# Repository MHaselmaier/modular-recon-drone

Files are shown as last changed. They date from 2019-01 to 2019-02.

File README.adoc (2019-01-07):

= Modular Recon Code Repository

Implementation of the drone functionality.

== Required libraries
The project is based on the ESP32 SoC by Espressif. It is possible to use the Arduino IDE to write software for the ESP32 but many developers already experienced a bad support for the chip. The recommanded way is to use Espressif's ESP-IDF. The IDF is a SDK that contains many wrappers for the chips functionality, e.g.: 

* FreeRTOS -> real time operating system for embedded devices
** Tasks
** Semaphores
** Concurrent queues
* TCP/IP stack
** Socket implementation provided by lwip (lightweight ip)
* GPIO abstraction 
* System wide event handler

An instruction on how to install the ESP-IDF is found on their https://esp-idf.readthedocs.io/en/latest/get-started/index.html#setup-toolchain[official developers page].

== Motor Controller

== Main Control Unit
=== Basic Makefile usage
The ESP-IDF provides a pre configured Makefile environment. 

*Build*: make all

*Flash*: make flash -> Implicitly triggers build process

*Clean*: make clean

*Monitor*: make monitor -> ESP toolchain monitor. Use in own terminal as it cannot be killed

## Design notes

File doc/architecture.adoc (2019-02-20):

== Architektur
=== Main Control Unit
Die MCU ist die Hauptkontrolleinheit. Ihre Hauptaufgaben sind: 
* Hosten eines Access Points
* Hosten eines UDP-Sockets
* Hosten eines TCP-Servers
* Hosten des TWI Master

Grundlage der MCU bildet ein _Espressif ESP32_ (DevKit v.1, siehe <<fig:esp32_devkitv1>>).

.Espressif ESP32 DevKit v1 Development Board
[[fig:esp32_devkitv1, {counter:fig}]]


Im Detail stellt der ESP32 einen Access Point mit WPA2 PSK Sicherung zur Verfügung. Das Passwort AP wird hierbei mittels 
des Hardware RNG in Form einer achtstelligen positiven Ganzzahl generiert. 
Das Passwort und die SSID des AP werden auf dem Bildschirm (siehe Abbildung <<sec:oled_screen>>) dargestellt. 

==== Entwicklung
Der ESP32 ist mit 244 Mhz und zwei CPU Kernen ein relativ potenter 32 Bit Microcontroller. Zudem verfügt der Controller 
über eine Vielzahl an Schnittstellen. Neben den oben erwähnten Funktionalitäten, verfügt der ESP noch über: 

* Bluetooth 4.2 (inkl. BLE)
* 18 ADC Kanäle mit 12 bit Auflösung
* 2 DAC mit 8 bit Auflösung
* 10 Touch Sensoren (Kapazitiv)
* 4 SPI Controller
* 2 TWI Controller
* 2 I^2^S Controller
* 3 UART Controller
* SD/SDIO/MMC/eMMC Host Controller 
* CAN Bus 2.0
* Motor und LED PWM
* Hall Effekt Sensor
* Hardwarebeschleunigte Kryptografie (AES, SHA-2, RSA, ECC, RNG)

Software für den ESP32 kann mit Hilfe der Arduino IDE entwickelt werden. Jedoch ist das SDK des Herstellers, auch als ESP-IDF bezeichnet, vorzuziehen, da 
sie der Arduino IDE gegenüber wesentlich mächtiger ist. 

==== ESP-IDF
Die Installation der ESP-IDF ist unter den gängigen Betriebssystemen mit Hilfe der 
Anleitung auf der Herstellerseite (siehe <<esp_idf_install>>) unkompliziert möglich. Dem SDK liegt zusätzlich noch eine Ansammlung an Beispielprojekten, sortiert nach Modulen (Wifi, Bluetooth, GPIO, etc) bei. Diese sind, wie auch die Komponenten der SDK selbst (Header Dateien) umfangreich und gut dokumentiert. Beim Aufsetzen eines neuen Projektes empfiehlt es sich, eines der Beispielprojekte zu nehmen (im Zweifelsfall das Hello World), da die ESP-IDF bereits eine auf Make basierende Buildchain anbietet. 

Diese lässt sich mit folgenden Befehlen bedienen (aus dem Projektverzeichnis heraus):

* make menuconfig -> TUI zur Konfiguration des Projektes (sdkconfig.h)
* make all -> Bau des Projektes
* make flash -> ggf. Bau des Projektes und Flashen des ESP
* make clean -> Bereinigung des Build-Verzeichnisses
* make monitor -> Starten des pythonbasierten seriellen Monitors

Um die Buildchain des SDK ohne Einschränkungen verwenden zu können, wird eine Python 2 installation benötigt. Diese sollte entsprechend unter Verwendung von _menuconfig_ unter _SDK Tool Configuration_ -> _Python 2 Interpreter_ gesetzt werden.

Danach muss noch der serielle Port, unter dem der ESP im Betriebssystem angebunden wird, konfiguiert werden. Dies geschieht unter _Serial flasher options_ -> _Default serial port_.

Die ESP-IDF nutzt das Echtzeitbetriebssystem FreeRTOS (siehe <<freertos>>). Dieses stellt Tasks, Message Queues zur Intertaskkommunikation, Tasksynchronisationsmechanismen (Mutex, etc) zur Verfügung.

Als TCP/IP Stack wird LwIP (siehe <<lwip>>) genutzt. Es handelt sich um eine leichtgewichtige Implementierung, deren Fokus auf Embedded Systems gelegt ist. Angelehnt ist die API an die der POSIX sockets.

==== MCU Software
Die Struktur des Projektes stellt sich wie folgt dar:

* main_control_unit
** components
*** camera 
*** u8g2
** main

Für das Ansprechen der Komponenten Kamera (siehe Abschnitt <<sec:camera_module>>) und Display (siehe Abschnitt <<sec:oled_display>>) wurden 
jeweils entsprechende externe Bibliotheken verwandt (näheres in den entsprechenden Kapiteln). Diese sind, wie andere externe Bibliotheken im Allgemeinen, im Ordner _components_ abgelegt. 
Der eigentliche Code der Drohne befindet sich im Ordner _main_. Der Aufbau der eigentlichen Projektdateien ist in Abbildung <<fig:mcu_structure>> definiert.

.MCU Code Struktur
[[fig:mcu_structure, {counter:fig}]]
[ditaa, "mcu_structure"]
....
+---------+                      +---------+
| drone.c |----------------------| drone.h |
+---------+                      +---------+
                                   | | | |
        /--------------------------/ | | \----------------------------\
        |                   /--------/ \-------\                      |
        |                   |                  |                      |
+---------------+  +-----------------+  +--------------+  +-------------------------+
| accesspoint.c |  | camera_module.c |  | i2c_master.c |  | udp_motor_data_server.c |
+---------------+  +-----------------+  +--------------+  +-------------------------+
....

Zunächst werden die Komponenten initialisiert. Nach der Initialisierung werden die einzelnen Module (accesspoint.c, etc) gestartet. 
Hierbei werden entsprechend für die einzelnen Module jeweils Tasks generiert um möglichst parallel zu laufen.

===== Access Point

===== Motor Control

===== Camera 

[plantuml]
....
@startuml
Main -> init: calls
@enduml
....

=== Motor Controller
Um die beiden Motoren anzusteuern, wurde ein ATTiny25 Mikrocontroller pro Motor verwendet.
Über das TWI wird den beiden Mikrocontrollern die gewüschte Richtung und Geschwindigkeit von
der MCU mitgeteilt. Sie werden über die Adressen 0x01 und 0x02 angesprochen. Auf Abbildung
<<fig:attiny25_pinout>> sind die Pins für die Takt- (_SCL_) und Datenleitung (_SDA_) des TWIs gezeigt.
Da die ATTinys nicht über eine Hardwareimplementierung des TWIs verfügen, musste sie in Software realisiert
werden. Hierzu wurde eine bereits existierende Implementation von <<twi_implementation>> verwendet, welche
die USI Schnittstelle der Mikrocontroller passend für das TWI konfiguriert (siehe <<attiny254585>>).

.ATTiny25 Pinout
[[fig:attiny25_pinout,{counter:fig}]]
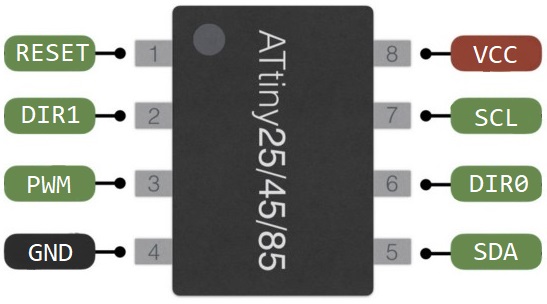
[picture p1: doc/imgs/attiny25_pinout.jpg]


Die ATTinys erwarten ein Byte, in dem die Richtung und die Geschwindigkeit kodiert sind.
Das höchstwertige Bit kodiert die Richtung. Wird eine _0_ empfangen, wird der Pin _DIR0_ auf _HIGH_
gesetzt und der Pin _DIR1_ auf _LOW_ gesetzt. Wird eine _1_ empfangen, wird enstprechend Pin _DIR0_
auf _LOW_ und Pin _DIR1_ auf _HIGH_ gesetzt. Diese beiden Pins sind nie zeitgleich _HIGH_. Durch die 
unteren sieben Bit des empfangenen Bytes wird die Geschwindigkeit in Prozent angegeben. Intern
betreiben die Mikrocontroller hiermit eine Pulsweitenmodulation, welche 127 Schritte unterstützt.
Dieses Signal wird über den Pin _PWM_ ausgegeben. Zwischen den ATTinys und dein Motoren wurde eine
H-Brücken eingebaut, um die Motoren mit 11.1V betreiben zu können. Wie die beiden Mikrocontroller 
über die H-Brücke mit den beiden Motoren verbunden ist, ist auf Abbildung <<fig:motor_controller_schematic>>
gezeigt.

.Schaltplan der Motorsteuerung
[[fig:motor_controller_schematic, {counter:fig}]]
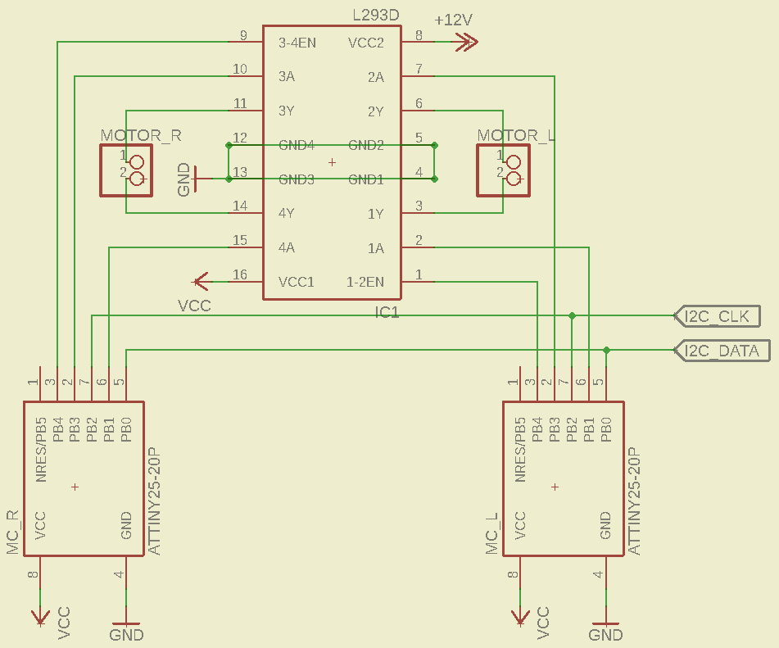
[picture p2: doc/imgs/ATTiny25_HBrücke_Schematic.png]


Der Programmcode für beide Mikrocontroller ist identisch. Die Adresse für das TWI wird
über das Define-Flag _address_ gesetzt werden. Um das Kompilieren des Programms für die 
beiden Mikrocontroller zu erleichtern, wurde ein Makefile erstellt. Durch den _make_
Befehl werden die Programm der beiden Mikrocontroller gebaut. Durch _make flash_L_ und
_make flash_R_ wird entsprechend das Programm für die linke und rechte Motorsteuerung 
auf die Mikrocontroller geschrieben. Damit das Kompilieren und Programmieren der ATTinys
funktioniert, müssen die AVR-Entwicklungstools _avr-gcc_, _avr-objcopy_ und _avrdude_ 
installiert sein. Bevor die Programme auf die Mikrocontroller geschrieben werden können,
muss sichergestellt werden, dass der Port des Programmers richtig gesetzt ist. Hierzu
kann das _-P_-Flag des _avrdude_-Befehls angepasst werden. Je nachdem, welche Programmer 
verwendet wird, muss auch das _-c_-Flag angepasst werden. In der aktuellen Version wird
davon ausgegangen, dass mit einem AVRISP programmiert wird (siehe <<arduino_programmer>>).

[[sec:camera_module]]
=== Kameramodul
Das Kameramodul basiert auf dem OV7725 VGA Sensor von Omnivision. 

.Anschluss der Kamera am ESP32
[width="75%", align="center"]
|===
|Kamera Pin |ESP32 Pin | |Kamera Pin | ESP32 Pin

|SIOC
|GPIO23
|
|SIOD
|GPIO25

|XCLK
|GPIO27
|
|VSYNC
|GPIO22

|HREF
|GPIO26
|
|PCLK
|GPIO21

|D2
|GPIO35
|
|D3
|GPIO17

|D4
|GPIO34
|
|D5
|GPIO5

|D6
|GPIO39
|
|D7
|GPIO18

|D8
|GPIO36
|
|D9
|GPIO19

|RESET
|GPIO15
|
|PWDN
| (über 10kOhm Widerstand auf GND)

|3.3V
|3.3V
|
|GND
|GND
|===

.Kameramodul OV7725
[[fig:camera_module, {counter:fig}]]
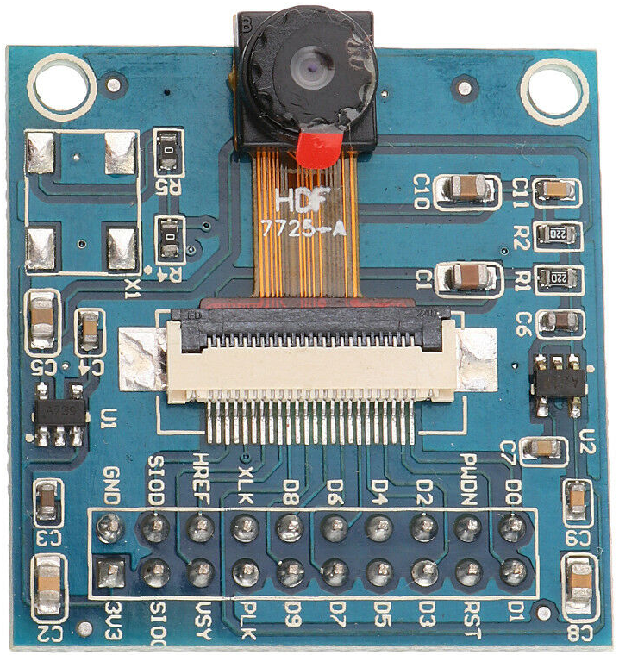
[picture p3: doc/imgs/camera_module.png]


[[sec:oled_display]]
=== Bildschirm
Verwendung findet ein monochromes OLED-Display mit einer Auflösung von 128x64 Pixel. Dieses basiert auf dem verbreiteten SSD1306 Controller. 

.Oled Diplay 128x64, SSD1306
[[fig:oled_display, {counter:fig}]]
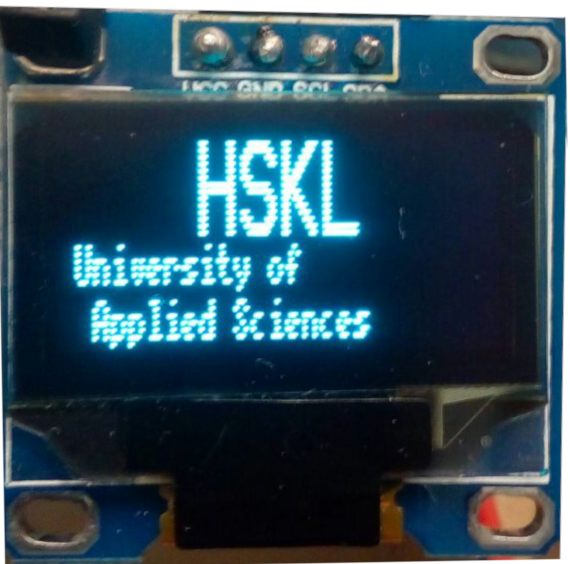
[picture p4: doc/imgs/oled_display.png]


Das Display wird hierbei über einen TWI-Bus angebunden. Entsprechend Pinout setzt sich wie folgt zusammen:

* GND: Ground, Masse
* VCC: Spannung, 3,3V - 5V
* SDL: TWI, Datenleitung
* SCL: TWI, Taktleitung

=== Stromversorgung
Im gesamten Projekt werden drei Versorgungsspannungen benötigt: 3.3V für das Kameramodul, 5V für die MCU und die Motorsteuerung und
bis zu 12V für die Motoren. Auf Abbildung <<fig:powersupply>> wird gezeigt, wie die einzelnen Versorgungsspannungen von der Batterie
erhalten werden.

.Stromversorgung
[[fig:powersupply, {counter:fig}]]
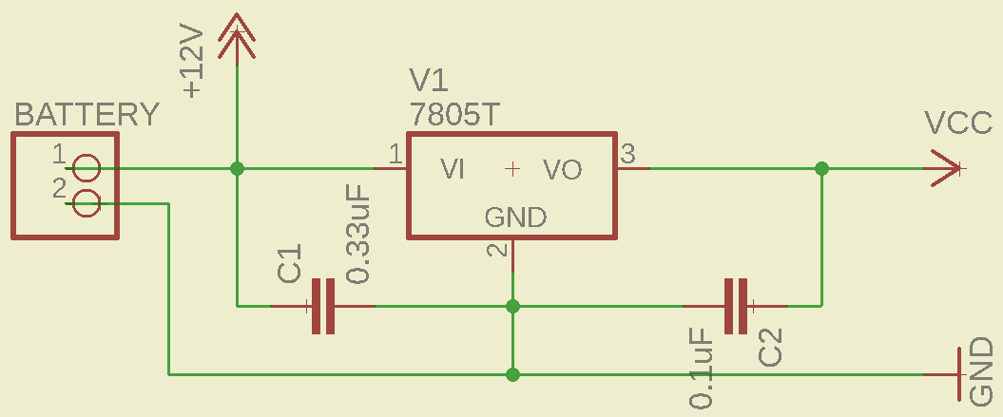
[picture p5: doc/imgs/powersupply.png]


Die Motoren werden direkt mit der Batteriespannung betrieben. Um die 5V für die MCU und die Motorsteuerung zu erhalten, wurde der
Spannungsregler 7805 verwendet. Er benötigt mindest 7V als Eingangspannung, um 5V als Ausgungsspannung zu erzeugen. Um ein Schwanken
der Betriebsspannungen zu vermeiden wurden Kondensatoren vor dem Ein- und Ausgang des Spannungsreglers platziert. Die für das
Kameramodul nötigen 3.3V werden von der MCU erzeugt. Bei der Realisierung dieses Projektes wurde sich für einen 3-Zellen LiPo-Akku
entschieden, wodurch 11.1V als Batteriespannung anliegen.

=== Schaltplan und PCB
Zu Beginn des Projekts wurden die einzelnen Komponenten auf einem Breadboard verkabelt und getestet und anschließend auf einer
Lochrasterplatine in einem Prototypen verlötet. Dieser Prototyp ist auf Abbildung <<fig:prototyp>> zu sehen.

.Lochrasterplatine
[[fig:prototyp, {counter:fig}]]
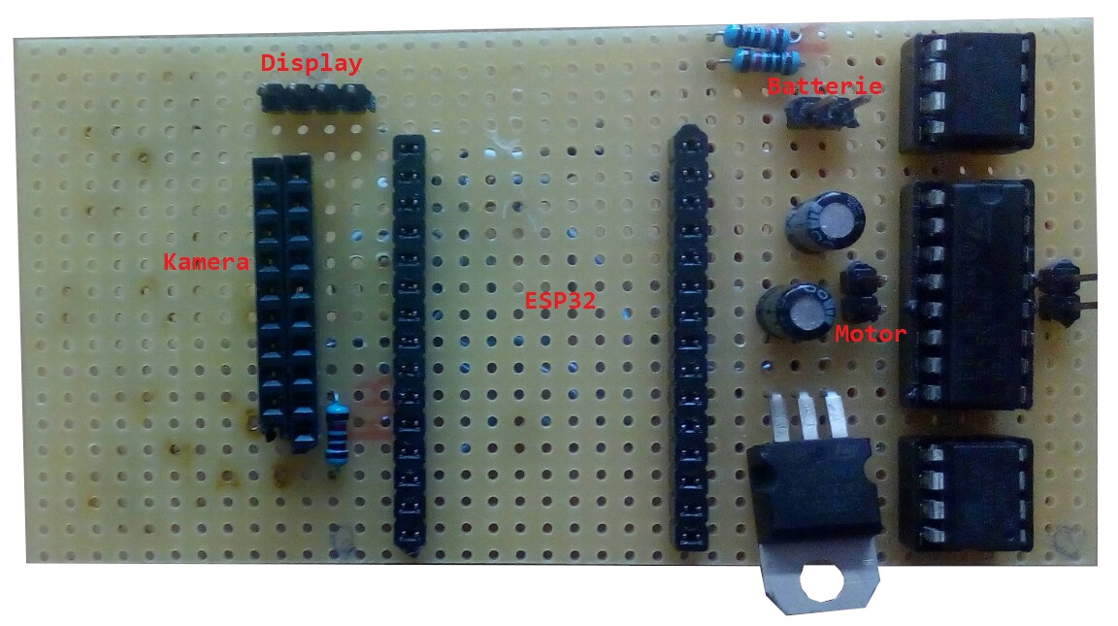
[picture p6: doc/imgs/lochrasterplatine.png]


Nachdem die Funktionalität des Aufbaus der Hardware verifiziert wurde, wurde ein PCB mit der Eagle Software von Autodesk designed
(siehe <<eagle>>). Die Eagle-Projektdateien sind im Ordner _schematic_and_pcb_ zu finden. Anschließend wurde JLCPCB (siehe <<jlcpcb>>)
mit der Fertigung des PCBs beauftragt. Das fertig bestückte PCB ist auf Abbildung <<fig:pcb>> gezeigt.

.Fertige bestücktes PCB
[[fig:pcb, {counter:fig}]]


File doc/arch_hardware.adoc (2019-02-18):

== Hardware
=== Main Control Unit
Die MCU ist die Hauptkontrolleinheit. 

=== Motor Controller
Um die beiden Motoren anzusteuern, wurde ein ATTiny25 Mikrocontroller pro Motor verwendet.
Über das TWI wird den beiden Mikrocontrollern die gewüschte Richtung und Geschwindigkeit von
der MCU mitgeteilt. Sie werden über die Adressen 0x01 und 0x02 angesprochen. Auf Abbildung
<<fig:attiny25_pinout>> sind die Pins für die Takt- (_SCL_) und Datenleitung (_SDA_) des TWIs gezeigt.
Die ATTinys erwarten ein Byte, in dem die Richtung und die Geschwindigkeit kodiert sind.

.ATTiny25 Pinout
[fig:attiny25_pinout]


Das höchstwertige Bit kodiert die Richtung. Wird eine _0_ empfangen, wird der Pin _DIR0_ auf _HIGH_
gesetzt und der Pin _DIR1_ auf _LOW_ gesetzt. Wird eine _1_ empfangen, wird enstprechend Pin _DIR0_
auf _LOW_ und Pin _DIR1_ auf _HIGH_ gesetzt. Diese beiden Pins sind nie zeitgleich _HIGH_. Durch die 
unteren sieben Bit des empfangenen Bytes wird die Geschwindigkeit in Prozent angegeben. Intern
betreiben die Mikrocontroller hiermit eine Pulsweitenmodulation, welche 127 Schritte unterstützt.
Dieses Signal wird über den Pin _PWM_ ausgegeben. Zwischen den ATTinys und dein Motoren wurde eine
H-Brücken eingebaut, um die Motoren mit 11.1V betreiben zu können. Wie die beiden Mikrocontroller 
über die H-Brücke mit den beiden Motoren verbunden ist, ist auf Abbildung <<fig:motor_controller_schematic>>
gezeigt.

.Schaltplan der Motorsteuerung
[fig:motor_controller_schematic]


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

=== Kameramodul
Das Kameramodul basiert auf dem OV7725 VGA Sensor von Omnivision. 

.Kameramodul OV7725
[fig:camera_module]


=== Bildschirm
Verwendung findet ein monochromes OLED-Display mit einer Auflösung von 128x64 Pixel. Dieses basiert auf dem verbreiteten SSD1306 Controller. 

.Oled Diplay 128x64, SSD1306
[fig:oled_display]


Das Display wird hierbei über einen TWI-Bus angebunden. Entsprechend Pinout setzt sich wie folgt zusammen:

* GND: Ground, Masse
* VCC: Spannung, 3,3V - 5V
* SDL: TWI, Datenleitung
* SCL: TWI, Taktleitung

=== Stromversorgung
Im gesamten Projekt werden drei Versorgungsspannungen benötigt: 3.3V für das Kameramodul, 5V für die MCU und die Motorsteuerung und
bis zu 12V für die Motoren. Auf Abbildung <<fig:powersupply>> wird gezeigt, wie die einzelnen Versorgungsspannungen von der Batterie
erhalten werden.

.Stromversorgung
[fig:powersupply]


Die Motoren werden direkt mit der Batteriespannung betrieben. Um die 5V für die MCU und die Motorsteuerung zu erhalten, wurde der
Spannungsregler 7805 verwendet. Er benötigt mindest 7V als Eingangspannung, um 5V als Ausgungsspannung zu erzeugen. Um ein Schwanken
der Betriebsspannungen zu vermeiden wurden Kondensatoren vor dem Ein- und Ausgang des Spannungsreglers platziert. Die für das
Kameramodul nötigen 3.3V werden von der MCU erzeugt. Bei der Realisierung dieses Projektes wurde sich für einen 3-Zellen LiPo-Akku
entschieden, wodurch 11.1V als Batteriespannung anliegen.

=== Schaltplan und PCB
Zu Beginn des Projekts wurden die einzelnen Komponenten auf einem Breadboard verkabelt und getestet und anschließend auf einer
Lochrasterplatine in einem Prototypen verlötet. Dieser Prototyp ist auf Abbildung <<fig:prototyp>> zu sehen.

.Lochrasterplatine
[fig:prototyp]


Nachdem die Funktionalität des Aufbaus der Hardware verifiziert wurde, wurde ein PCB mit der Eagle Software von Autodesk designed
(siehe <<eagle>>). Die Eagle-Projektdateien sind im Ordner _schematic_and_pcb_ zu finden. Anschließend wurde JLCPCB (siehe <<jlcpcb>>)
mit der Fertigung des PCBs beauftragt. Das fertig bestückte PCB ist auf Abbildung <<fig:pcb>> gezeigt.

.Fertige bestücktes PCB
[fig:pcb]


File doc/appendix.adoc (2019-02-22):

<<<
== Anhang

.PCB Oberseite
[[fig:pcb_front,{counter:fig}]]
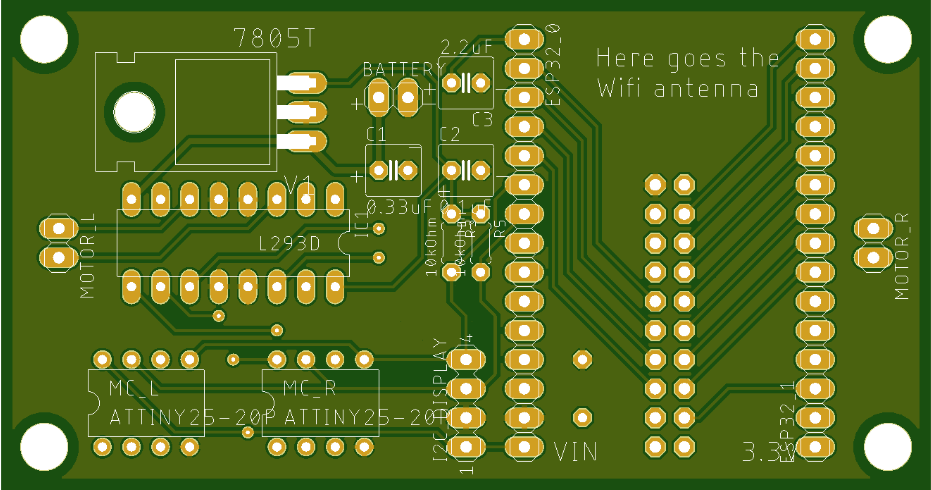
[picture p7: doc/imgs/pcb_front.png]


.PCB Unterseite
[[fig:pcb_back,{counter:fig}]]
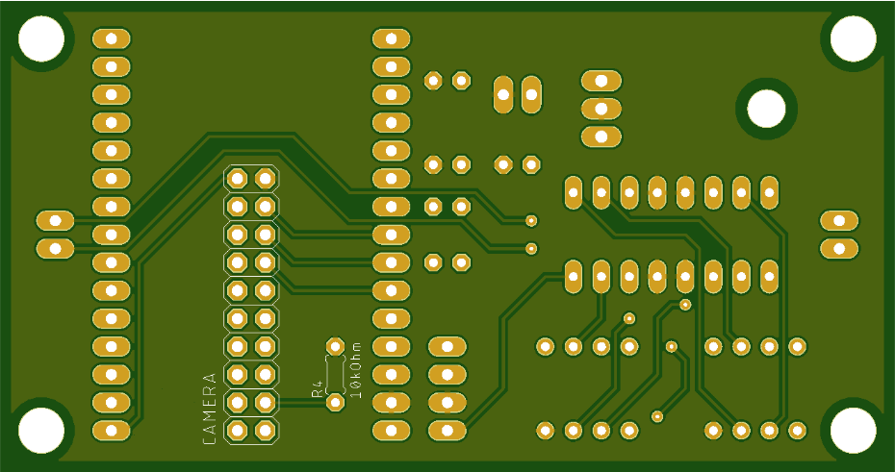
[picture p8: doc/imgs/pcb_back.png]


.Kompletter Schaltplan
[[fig:full_schematic,{counter:fig}]]
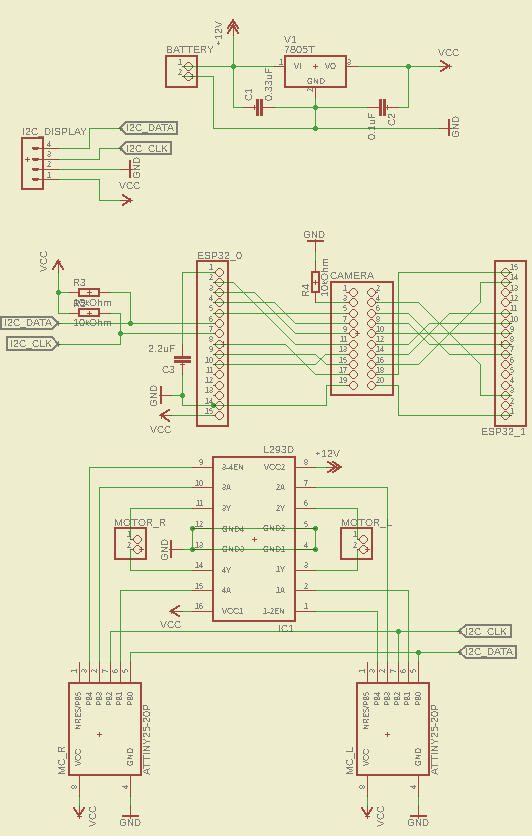
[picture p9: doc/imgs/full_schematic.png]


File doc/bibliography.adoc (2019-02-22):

<<<
[bibliography]
== Quellen
- [[[u8g2]]] Graustufenbildschirm Bibliothek: https://github.com/olikraus/u8g2
- [[[u8g2_esp]]] esp idf wrapper: https://github.com/nkolban/esp32-snippets/tree/master/hardware/displays/U8G2
- [[[esp_cam]]] esp idf Kamera Bibliothek: https://github.com/igrr/esp32-cam-demo.git
- [[[arduino_programmer]]] Arduino Uno als Programmer: https://create.arduino.cc/projecthub/arjun/programming-attiny85-with-arduino-uno-afb829
- [[[eagle]]] Eagle Software: https://www.autodesk.co.uk/products/eagle/overview
- [[[twi_implementation]]] TWI Implementation: https://github.com/rambo/TinyWire
- [[[attiny254585]]] ATTiny25/45/85 Datenblatt: https://ww1.microchip.com/downloads/en/DeviceDoc/Atmel-2586-AVR-8-bit-Microcontroller-ATtiny25-ATtiny45-ATtiny85_Datasheet.pdf
- [[[esp_idf_install]]] ESP-IDF Getting Started: https://docs.espressif.com/projects/esp-idf/en/latest/get-started/index.html
- [[[freertos]]] FreeRTOS, Dokumentation: https://www.freertos.org/Documentation/RTOS_book.html
- [[[lwip]]] LwIP TCP/IP Stack: https://savannah.nongnu.org/projects/lwip/
- [[[openscad]]] OpenSCAD: http://www.openscad.org/
- [[[ov7725]]] OV7725 Sensor: https://www.ovt.com/sensors/OV7725
- [[[esp32_kevin]]] Projekterfahrung EspressifESP32 –Fallbeispiel "Kevin", arendi, Benno Trutmann: https://www.swisst.net/fileadmin/swissTmeetings/ECC2018/Referate/2B1_Trutmann_Arendi.pdf
- [[[light_barrier_img]]] Bild, Lichtschranke, rs-online: https://de.rs-online.com/web/p/products/1254555/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
- [[[rotary_encoder_img]]] Encoder Scheibe, eckstein-shop: https://eckstein-shop.de/Adafruit-TT-Motor-Getrieb-DC-Motor-Encoder-Pack-of-2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

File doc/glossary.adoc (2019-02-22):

<<<
[glossary]
== Glossar

[glossary]
TWI:: Two Wire Interface (bekannt als I^2^C), zweiadriger Master-Slave Bus
MCU:: Main Control Unit
PCB:: Printed Ciruit Board
USI:: Universial Serial Interface
BLE:: Bluetooth Low Energy
ADC:: Analog Digital Converter
DAC:: Digital Analog Converter
PWM:: Pulse Width Modulation
AP:: Access Point
RNG:: Random Number Generator
SDK:: Software Development Kit
THT:: Through Hole Technology, Durchsteckmontage
FPS:: Frames per Second
SCCB:: Serial Camera Control Bus
SPI:: Serial Peripheral Interface

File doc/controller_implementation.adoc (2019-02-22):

== Entwicklung einer Steuerung

Aufgrund der schlichten Schnittstelle zur Drohne ist es sehr einfach, eine
beliebige Steuerung zu implementieren. Um die Drohne anzusteuern, muss sich 
zuerst mit dem bereitgestellten W-Lan-Netzwerk verbunden werden. Innerhalb
dieses Netzwerkes hat die Drohne immer die IP-Addresse _192.168.4.1_. Um 
das Kamerasignal zu erhalten, muss eine TCP-Verbindung zur Drohne über 
Port _1234_ aufgebaut werden. Die Drohne sendet das Bildsignal Byteweise
an den Client. Das übersendete Bild ist im Grayscale-Format und besitzt eine
Auflösung von 160x120 Pixeln. Um die Drohne zu steuern, müssen ihr zwei 
Bytes per UDP über Port 4242 übertragen werden. Das erste Byte steuert den linken Motor
und das zweite Byte steuert den rechten Motor (vgl. Abbildung <<fig:udp-packet>>).

[[fig:udp-packet, {counter:figure-counter}]]
[ditaa, udp-packet, align="center"]
.UDP-Paketformat
....
 <--1 bit--> <-7 bit-> <--1 bit--> <-7 bit->
+-------------------------------------------+
| Direction |  Speed  | Dircetion |  Speed  |
+-------------------------------------------+
 <----left motor-----> <----right motor---->
....

Das _Direction_ bit gibt an, ob die Motoren vorwärts (0) oder rückwärst (1) drehen.
In den sieben _Speed_ bits wird die prozentuale Geschwindigkeit definiert, also ein
Wert im Intervall [0, 100]. Um die Drohne um Hindernisse zu manövrieren, muss die 
Geschwindigkeit der beiden Motoren unterschiedlich hoch definiert werden.

Im Folgenden wird eine Referenzimplementierung der Drohnensteuerung am Beispiel
einer Android App und einer Desktopanwendung beschrieben.

=== Referenzimplementierung für Android

Zur Steuerung der Recon Drone wurde eine simple Android App entwickelt.
Sie besteht im Grunde aus zwei Ansichten, eine zum Verbinden mit der Drohne
und eine zum Steuern der Drohne. Beide Ansichten sind auf Abbildung <<fig:app>>
gezeigt. Die App sucht nach dem W-Lan-Netzwerk, das von der Drohne bereitgestellt
wird. Damit W-Lan-Netzwerke gesucht werden können, muss der Standort-Service des
Smartphones aktiviert sein. Wurde das Netzwerk gefunden, wird das Passwort zum 
Verbinden verlangt. Wurde das Passwort eingegeben und der "Verbinden"-Button 
gedrückt, baut die App die Verbindung zur Drohne auf. Damit die App mit der Drohne
kommunizieren kann, muss das mobile Internet deaktiviert sein. Diese Funktionalität
wird durch die _ReconDroneConnection_-Klasse realisiert (vgl. Abbildung <<fig:classdiagram>>).
Hat sich das Smartphone mit der Drohne verbunden, wird automatisch zur nächsten Ansicht der
App gewechselt, welche durch die _ReconDrone_-Klasse realisiert wird.

.Ansichten der App
[[fig:app,{counter:fig}]]
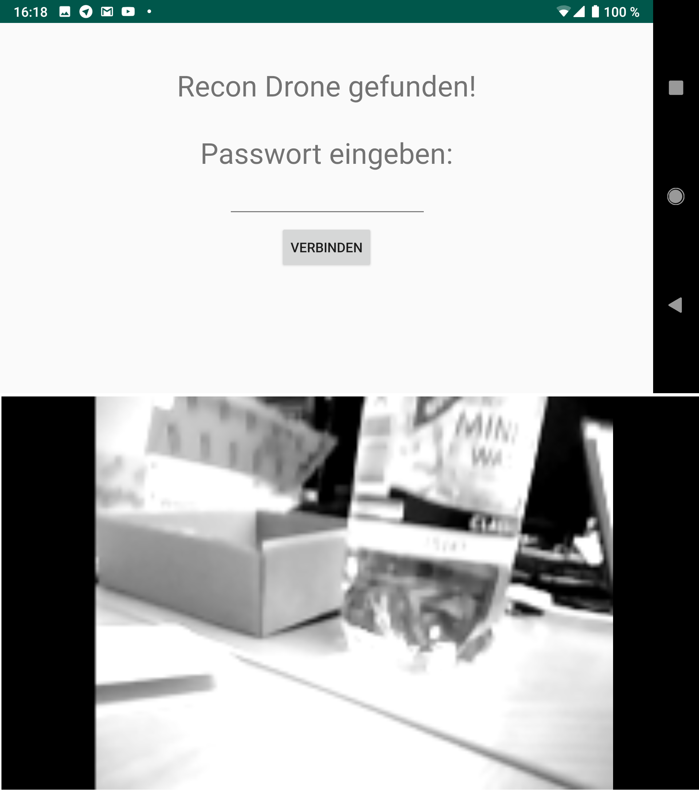
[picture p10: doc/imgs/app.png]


Aus dieser zweiten Ansicht kann die Drohne gesteuert werden und das Kamerasignal 
eingesehen werden. Die Steuerung wird von der _TouchController_-Klasse implementiert.
Die Touchevents des Benutzer werden in der _onTouch()_-Methode verarbeitet. In ihr 
werden die Startpositionen und die aktuellen Positionen der Touchbewegungen verarbeitet und 
in den Attributen _startingPositions_ und _currentPositions_ zwischengespeichert.
Die komplette rechte Hälfte des Bildschirms dient zur Beschleunigung
der Drohne. Je weiter der Finger vom Startpunkt der Touchbewegung entfernt ist, desto 
schneller bewegt sich die Drohne. Die linke Hälfte des Bildschirms dient zur Lenkung
der Drohne. In den Attributen _accerleration_ und _steering_ wird die ID des jeweiligen 
Touchevents gespeichert. Wenn kein Touchevent vorliegt, enthalten die beiden Attribute
den Wert -1. Alle 50 Millisekunden wird die Methode _sendControllerUpdate()_ aufgerufen,
welche der Drohne die Steuersignale sendet. Es werden zwei Bytes übertragen, die jeweils 
die Geschwindigkeit und Richtung für einen Motor definieren. Die beiden Bytes werden in 
den Methoden _setAcceleration()_, _setSteering()_, _setDirection()_ und _adjustForInPlaceTurn()_
befüllt.

[[fig:classdiagram,{counter:fig}]]
[plantuml, diagram-classes, png, align="center"]
.Klassendiagramm
....
@startuml
skinparam classAttributeIconSize 0
class ReconDroneConnection extends Activity {
    - status: TextView
    - passwordLabel: TextView
    - password: EditText
    - connect: Button
    - wifiManager: WifiManager
    - handler: Handler
    - removeReconDroneNetwork()
    - foundReconDrone()
    - lostReconDrone()
    - searchForReconDrone()
}
class ReconDrone extends Activity {
    - enableFullScreen()
}
class TouchController implements OnTouchListener {
    - context: Context
    - acceleration: int
    - steering: int
    - startingPositions: float[]
    - currentPositions: float[]
    + TouchController(context: Context)
    + onTouch(view: View, event: MotionEvent): boolean
    - getSideOfScreen(x: float): SIDE_OF_SCREEN
    - sendControllerUpdate()
    - setAcceleration(buffer: byte[])
    - setSteering(buffer: byte[])
    - setDirection(buffer: byte[])
    - adjustForInPlaceTurn(buffer: byte[])
}
enum SIDE_OF_SCREEN {
    LEFT
    RIGHT
}
class CameraFeed {
    - imageView: ImageView
    - handler: Handler
    - backgroundThread: Thread
    + CameraFeed(imageView: ImageView)
    + startFeed()
}

ReconDrone *-- TouchController : controller
TouchController +-- SIDE_OF_SCREEN
ReconDrone *-- CameraFeed : feed
@enduml
....

Das Kamerasignal der Drohne wird in der _CameraFeed_-Klasse verarbeitet. Sie nimmt in
ihrem Konstruktor das _ImageView_-Objekt entgegen, in dem sie das Kamerasignal anzeigen
soll. Sie startet einen Hintergrundthread, in dem die einzelnen Bilder empfangen werden
und wandelt die Byte-Daten in ein Bitmap um. Da in Android das User-Interface nicht aus
einem Hintergrundthread angepasst werden kann, wird ein _Handler_ verwendet, der das
Bitmap im _ImageView_ anzeigt.

Um die Android App zu installieren, muss die APK-Datei auf das Smartphone übertragen werden.
Sie befindet sich im Ordner _android_app/app/build/outputs/apk/debug_. Um sie zu installieren
muss in den Einstellungen des Smartphones die Installation von Apps aus unsicheren Quellen
erlaubt werden. Auf dem Smartphone muss mindestens Android 5.0 installiert sein. Die App wurde
unter Android 9.0 getestet.

=== Referenzimplementierung Desktop
Auch für den Desktop wurde eine simple Referenzimplementierung unter Verwendung des QT-Frameworks (QML) entwickelt. 
Diese baut nach dem Starten direkt eine Verbindung zum UDP- und TCP-Socket der Drohne auf. Zur Steuerung der Drohne bietet die Oberfläche zwei Slider an. Der obere regelt die Geschwindigkeit der Motoren von -100% bis 100%. Mit dem zweiten Slider, dem Balancer, kann die Richtung bestimmt werden, indem einer der Motoren verlangsamt wird.

[[fig:qt_drone_control, {counter:fig}]]
.Bedienoberfläche, DroneControl QT-Applikation
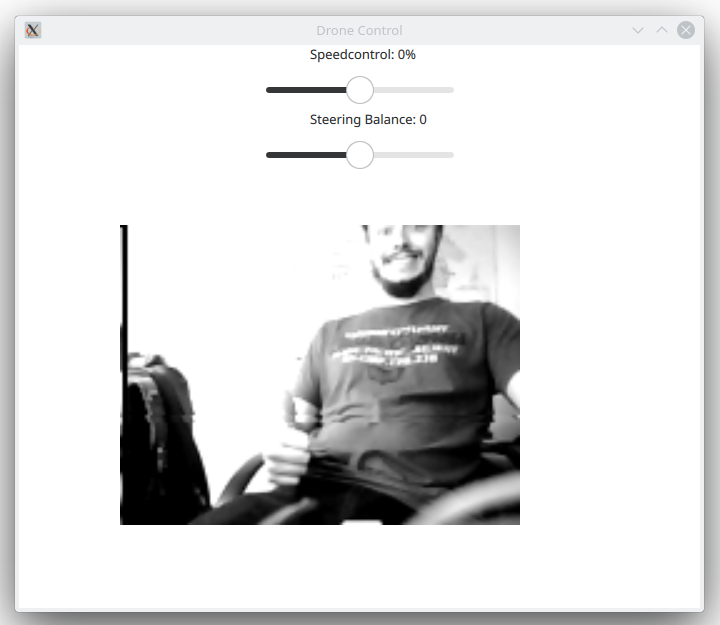
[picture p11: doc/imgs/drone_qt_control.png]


Neben der Steuerung über die Slider, lässt sich die Drohne auch mittels Gamepad steuern (siehe Abbildung <<fig:gamepad>>). Die Geschwindigkeit wird mit Hilfe der y-Achse des rechten Analogsticks gesteuert und die Balance, also die Richtung, mittels der x-Achse des linken Analogsticks. Auch eine rudimentäre Steuerung mittels Pfeiltasten ist möglich (jedoch nicht zu empfehlen).

[[fig:gamepad, {counter:fig}]]
.Verwendeter Gamepad-Typ
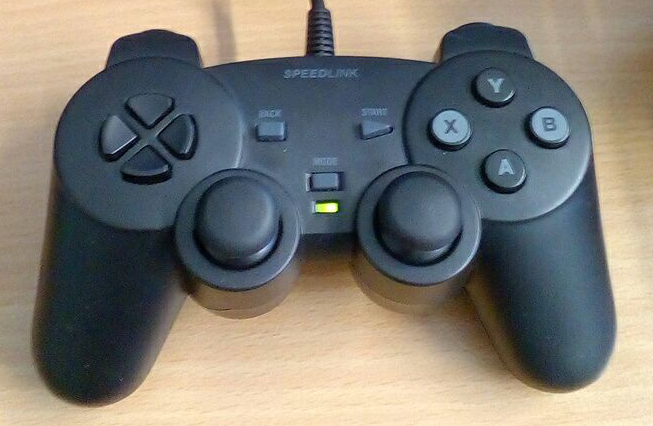
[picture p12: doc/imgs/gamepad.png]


Zum Bauen der Anwendung wird ein C++ Compiler, sowie das QT-Framework benötigt. Zusätzlich sollte die Zusatzbibliothek _qt5-gamepad_ installiert werden, da die Gamepad-Steuerung darauf basiert.

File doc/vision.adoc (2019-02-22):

== Ausblick
Auf Basis des derzeitigen Entwicklungsstands der Drohne lassen sich weitere Zusatzfunktionen und Verbesserungen implementieren. Einige 
Ideen sollen im Folgenden präsentiert werden.

=== Gehäuse
Derzeit ist das Chassis der Drohne noch im Prototypenzustand, gefertigt aus Stahllochblechprofilen. Diese Bauart ist zum Einen relativ schwer und bietet keinen Rundumschutz.
Es bietet sich deshalb an, ein Gehäuse mittels 3D-Druck anzufertigen. Während des Projektes wurde bereits eine erste Version des Gehäuses mittels CAD Software (siehe <<openscad>>)  modeliert. Dieses kann evaluiert und gedruckt werden oder durch ein anderes, völlig neues Design ersetzt werden. 

=== Verpolschutz
Im aktuellen Stand wird der LiPo-Akku mittels _Male Headern_ am PCB der Drohne angeschlossen. Der Akku verfügt über eine Buchse vom Typ _JST RCY_. Zum Einen könnte ein entsprechender _Female_ Verbinder für THT Platinen verbaut werden, um eine richtige Polung beim Anschließen zu garantieren. 
Zum Anderen kann mit Hilfe eines Brückengleichrichters (siehe Abbildung <<fig:bridge_rectifier>>) hinter dem Akkuanschluss ein Schutz vor Verpolung garantiert werden. 

.Diodenbrückengleichrichter
[[fig:bridge_rectifier, {counter:fig}]]
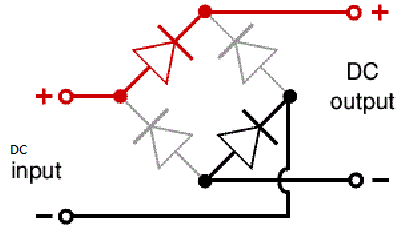
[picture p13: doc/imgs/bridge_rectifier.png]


Die Funktionsweise der Brücke ist relativ simple. Unabhängig davon, wie der Strom angelegt wird, schließt die Konfiguration der Dioden stets so, dass am Ausgang der Brücke Plus und Minus immer gleich anliegen. 
Eine Diode hat entsprechend die Eigenschaft, Strom in eine Richtung hin passieren zu lassen, während sie in entgegengesetzter Richtung den Stromfluss sperrt.

=== Raspberry PI zero W
Alternativ kann als MCU der Raspberry PI zero W evaluiert werden. Vorteil dieses Einplatinencomputers im Gegensatz zum ESP32 ist der wesentlich größere RAM, der das Puffern größerer Kamerabilddaten ermöglicht (siehe Abschnitt <<sec::camera_module>>).

=== Alternative Stromversorgung
Aktuell wird ein linearer Spannungsregler verwendet, um die hohe Batteriespannung von 11.1V auf die 5V
zu reduzieren, die von der MCU und den ATTinys benötigt werden. Hierbei wird sehr viel Energie
in Form von Wärme verschwendet. Dies beeinflusst die Batterielaufzeit der Drohne negativ. Weiterhin
besteht die Möglichkeit, dass der Spannungsregler überhitzt, in welchem Fall er sich abschalten
würde. Erst wenn er weit genug abgekühlt ist, gibt er wieder 5V aus. Dies würde zum Abschalten der
Drohne führen. Alternativ könnte ein _Step-Down-Converter_ oder auch _Buck-Converter_ verwendet werden.
Im Vergleich zu einem linearen Spannungsregler wird verschwendet diese Variante weniger Energie und erhöht
somit die Batterielaufzeit der Drohne. Allerdings wird die Schaltung etwas komplexer und die benötigten 
Komponenten kosten etwas mehr als ein linearer Spannungsregler.

[[sec:vision_external_ram]]
=== Externer SPI RAM
Das Kamerabild, das von der Drohne übertragen wird, kann aktuell eine maximale Auflösung von 320x240 Pixeln 
unterstützen, wenn es im Grayscale-Format übertragen wird. Diese Einschränkungen sind auf den begrenzten
internen RAM des ESP32 zurückzuführen. Er besitzt eine Größe von 320KB, welche sich in zwei Teile
unterteilt. Aufgrund von technischen Einschränkungen können maximal 160KB statisch allokiert werden. Die restlichen
160KB können nur während der Laufzeit dynamisch allokiert werden (vgl. <<esp32_kevin>>). Bei einer Auflösung von 320x240 Pixeln und einem
Byte für den Grauwert eines Pixels benötigt ein Bild bereits 76.8KB, um es vor dem Senden zwischenzuspeichern.
Ein farbiges Bild ist nicht möglich, da dies Aufgrund der 3 Bytes pro Pixel, eines pro Farbkanal, bei einer Größe von
230.4KB liegen würde. Wird versucht ein Byte-Array dieser Größe zu allokieren, gibt der ESP32 eine Fehlermeldung aus.
Es ist jedoch möglich, den internen RAM des ESP32 um einen externen RAM zu erweiteren, der über das SPI-Interface
angeschlossen wird. Ist der gewählte externe RAM groß genug, kann ein farbiges Bild in der maximalen Auflösung
des Sensors von 640x480 Pixeln aufgenommen werden. Hierfür werden 921,6KB benötigt.

=== Drehzahlkorrektur der Motordrehzahl
Da die Motoren bedingt durch geringfügige Fertigungsunterschiede (unterschiede in der Erregerwicklung, etc) laufen die Motoren bei gleichem PWM Signal nicht identisch schnell. Entsprechend hat die Drohne die Tendenz bei Geradeausfahrten in eine bestimmte Richtung zu fahren. 
Um diesem Verhalten entgegenzuwirken, muss der ESP32 anhand der tatsächlichen Drehzahl der Motoren Korrekturwerte an die Motorcontroller übergeben. Um die Drehzahl bei einem Gleichstrommotor zu ermitteln, können beispielsweise folgende Verfahren angewandt werden: 

*Back EMF - Back Electromotive Force*: Da ein PWM Signal den Motor nicht durchgehend mit Spannung versorgt, sondern nur in Intervalen, befindet sich der Motor auch immer in Phasen, in denen er keine Spannungsversorgung erhält. Bedingt durch die Trägheit dreht der Motor sich noch eine gewisse Zeit weiter. In dieser Phase generiert der Motor eine Spannung durch elektrische Induktion (siehe Induktionsgesetze von Michael Faraday, Joseph Henry und Hans Christian Ørsted und Lenzsche Regel nach Emil Lenz), dem Back EMF. Diese Spannung kann entsprechend von einem ADC eingelesen und interpretiert werden. Es ist zu beachten, dass die Spannung ggf. erst mittels Spannungsteiler auf ein für den Microcontroller sicher messbaren Spannungsbereich herunter bricht (max. 5V).

*Rotary Encoder*: Beim Rotary Encoder bzw. Drehgeber handelt es sich im einfachsten Fall um eine Scheibe mit Schlitzen in gleichen Abständen zueinander, wie in Abbildung <<fig:rotary_wheel>> gezeigt. Diese Scheibe ist an der Welle des Motors angebracht. 

.Drehgeber, Scheibe, <<rotary_encoder_img>>
[[fig:rotary_wheel, {counter:fig}]]
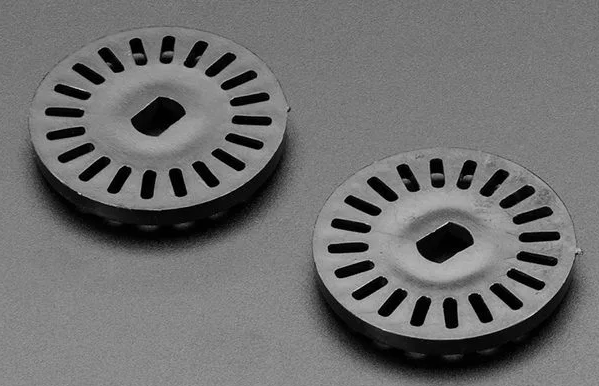
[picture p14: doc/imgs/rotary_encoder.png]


Die Schreibe dreht sich hierbei zwischen einer Lichtschranke, wie in Abbildung <<fig:light_barrier>>, die wiederum aufgrund der Schlitze in der Scheibe abwechselnt eine Spannung ausgibt oder nicht. Ausgelesen mit einem GPIO-Pin ergibt sich hieraus ein Signal in Sägezahnform, wobei die Frequenz der Flankenwechsel der Umdrehung des Motors entspricht.

.Drehgeber, Lichtschranke, <<light_barrier_img>>
[[fig:light_barrier, {counter:fig}]]
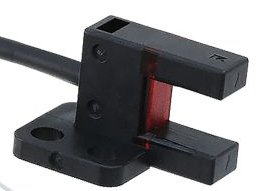
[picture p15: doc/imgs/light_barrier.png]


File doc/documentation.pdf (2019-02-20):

# Modular Recon Drone

# Dokumentation

Matthias Haselmaier, B.Sc. und Andreas M. Brunnet, B.Sc.

# Table of Contents

# Vorwort Architektur

# Main Control Unit

Die MCU ist die Hauptkontrolleinheit.

# Motor Controller

Um die beiden Motoren anzusteuern, wurde ein ATTiny25 Mikrocontroller pro Motor verwendet. Über das TWI wird den beiden Mikrocontrollern die gewüschte Richtung und Geschwindigkeit von der MCU mitgeteilt. Sie werden über die Adressen 0x01 und 0x02 angesprochen. Auf Abbildung {counter:fig} sind die Pins für die Takt- (SCL) und Datenleitung (SDA) des TWIs gezeigt. Da die ATTinys nicht über eine Hardwareimplementierung des TWIs verfügen, musste sie in Software realisiert werden. Hierzu wurde eine bereits existierende Implementation von [twi_implementation] verwendet, welche die USI Schnittstelle der Mikrocontroller passend für das TWI konfiguriert (siehe [attiny254585]).

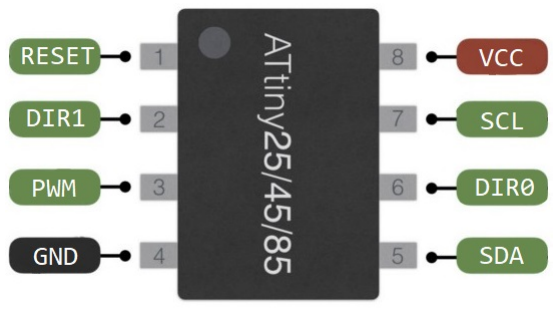
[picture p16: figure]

Abbildung 1. ATTiny25 Pinout

Die ATTinys erwarten ein Byte, in dem die Richtung und die Geschwindigkeit kodiert sind. Das höchstwertige Bit kodiert die Richtung. Wird eine 0 empfangen, wird der Pin DIR0 auf HIGH gesetzt und der Pin DIR1 auf LOW gesetzt. Wird eine 1 empfangen, wird enstprechend Pin DIR0 auf LOW und Pin DIR1 auf HIGH gesetzt. Diese beiden Pins sind nie zeitgleich HIGH. Durch die unteren sieben Bit des empfangenen Bytes wird die Geschwindigkeit in Prozent angegeben. Intern betreiben die Mikrocontroller hiermit eine Pulsweitenmodulation, welche 127 Schritte unterstützt. Dieses Signal wird über den Pin PWM ausgegeben. Zwischen den ATTinys und dein Motoren wurde eine H-Brücken eingebaut, um die Motoren mit 11.1V betreiben zu können. Wie die beiden Mikrocontroller über die H-Brücke mit den beiden Motoren verbunden ist, ist auf Abbildung {counter:fig} gezeigt.


Abbildung 2. Schaltplan der Motorsteuerung

Der Programmcode für beide Mikrocontroller ist identisch. Die Adresse für das TWI wird über das Define-Flag address gesetzt werden. Um das Kompilieren des Programms für die beiden Mikrocontroller zu erleichtern, wurde ein Makefile erstellt. Durch den make Befehl werden die Programm der beiden Mikrocontroller gebaut. Durch make flash_L und make flash_R wird entsprechend das Programm für die linke und rechte Motorsteuerung auf die Mikrocontroller geschrieben. Damit das Kompilieren und Programmieren der ATTinys funktioniert, müssen die AVR-Entwicklungstools avr-gcc, avr-objcopy und avrdude installiert sein. Bevor die Programme auf die Mikrocontroller geschrieben werden können, muss sichergestellt werden, dass der Port des Programmers richtig gesetzt ist. Hierzu kann das -P-Flag des avrdude-Befehls angepasst werden. Je nachdem, welche Programmer verwendet wird, muss auch das -c-Flag angepasst werden. In der aktuellen Version wird davon ausgegangen, dass mit einem AVRISP programmiert wird (siehe [arduino_programmer]).

# Kameramodul

Das Kameramodul basiert auf dem OV7725 VGA Sensor von Omnivision.

Abbildung 3. Kameramodul OV7725

# Bildschirm


Verwendung findet ein monochromes OLED-Display mit einer Auflösung von 128x64 Pixel. Dieses basiert auf dem verbreiteten SSD1306 Controller.

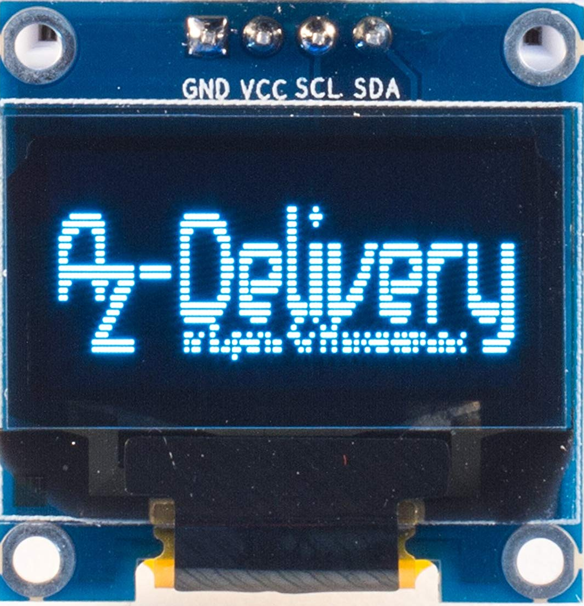
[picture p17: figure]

Abbildung 4. Oled Diplay 128x64, SSD1306

Das Display wird hierbei über einen TWI-Bus angebunden. Entsprechend Pinout setzt sich wie folgt zusammen:

- GND: Ground, Masse
- VCC: Spannung, 3,3V - 5V
- SDL: TWI, Datenleitung
- SCL: TWI, Taktleitung

# Stromversorgung

Im gesamten Projekt werden drei Versorgungsspannungen benötigt: 3.3V für das Kameramodul, 5V für die MCU und die Motorsteuerung und bis zu 12V für die Motoren. Auf Abbildung {counter:fig} wird gezeigt, wie die einzelnen Versorgungsspannungen von der Batterie erhalten werden.

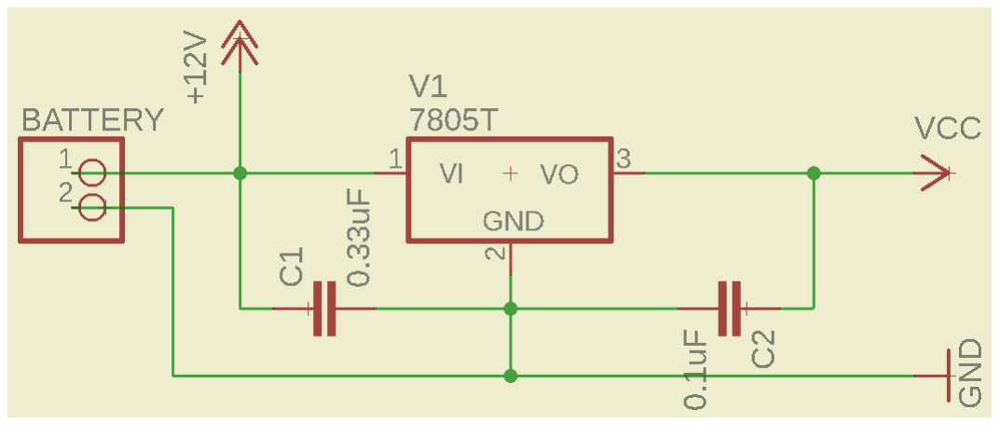
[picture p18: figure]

Abbildung 5. Stromversorgung

Die Motoren werden direkt mit der Batteriespannung betrieben. Um die 5V für die MCU und die Motorsteuerung zu erhalten, wurde der Spannungsregler 7805 verwendet. Er benötigt mindest 7V als Eingangspannung, um 5V als Ausgungsspannung zu erzeugen. Um ein Schwanken der Betriebsspannungen zu vermeiden wurden Kondensatoren vor dem Ein- und Ausgang des Spannungsreglers platziert. Die für das Kameramodul nötigen 3.3V werden von der MCU erzeugt. Bei der Realisierung dieses Projektes wurde sich für einen 3-Zellen LiPo-Akku entschieden, wodurch 11.1V als Batteriespannung anliegen.

# Schaltplan und PCB

Zu Beginn des Projekts wurden die einzelnen Komponenten auf einem Breadboard verkabelt und getestet und anschließend auf einer Lochrasterplatine in einem Prototypen verlötet. Dieser Prototyp ist auf Abbildung {counter:fig} zu sehen.

[lochrasterplatine] | lochrasterplatine.png
Abbildung 6. Lochrasterplatine

Nachdem die Funktionalität des Aufbaus der Hardware verifiziert wurde, wurde ein PCB mit der Eagle Software von Autodesk designed (siehe [eagle]). Die Eagle-Projektdateien sind im Ordner schematic_and_pcb zu finden. Anschließend wurde JLCPCB (siehe [jlcpcb]) mit der Fertigung des PCBs beauftragt. Das fertig bestückte PCB ist auf Abbildung {counter:fig} gezeigt.

[pcb] | pcb.png
Abbildung 7. Fertige bestücktes PCB

# Android App

Zur Steuerung der Recon Drone wurde eine simple Android App entwickelt. Sie besteht im Grunde aus zwei Ansichten, eine zum Verbinden mit der Drone und eine zum Steuern der Drone. Beide Ansichten sind auf Abbildung {counter:fig} gezeigt. Die App sucht nach dem W-Lan Netzwerk, dass von der Drone bereitgestellt wird. Damit W-Lan Netzwerke gesucht werden können, muss der Standort-Service des Smartphones aktiviert sein. Wurde das Netzwerk gefunden, wird das Passwort zum Verbinden verlagt. Wurde das Passwort eingegeben und der "Verbinden"-Button gedrückt, baut die App die Verbindung zur Drone auf. Damit die App mit der Drone kommunizieren kann, müssen die mobile Internet deaktiviert sein. Hat sich das Smartphone mit der Drone verbunden, wird automatisch zur nächsten Ansicht der App gewechselt.

[app] | app.jpg
Abbildung 8. Ansichten der App

Aus dieser zweiten Ansicht kann die Drone gesteuert werden und das Kamerasignal eingesehen werden. Die komplette rechte Hälfte des Bildschirms dient zur Beschleunigung der Drohne. Je weiter der Finger vom Startpunkt der Touchbewegung entfernt ist, desto schneller bewegt sich die Drohne. Die linke Hälft des Bildschirms dient zur Lenkung der Drone.

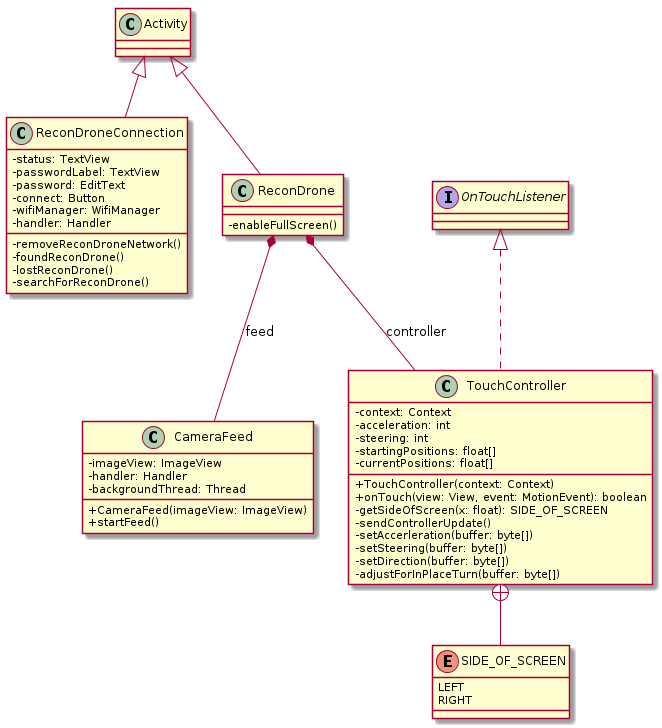
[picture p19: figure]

Abbildung 10. Test

# Ausblick Glossar

TWI
Two Wire Interface (bekannt als I² C), zweiadriger Master-Slave Bus

MCU
Main Control Unit

PCB
Printed Ciruit Board

USI
Universial Serial Interface

# Quellen

- [u8g2] Graustufenbildschirm Bibliothek: https://github.com/olikraus/u8g2
- [u8g2_esp] esp idf wrapper: https://github.com/nkolban/esp32-snippets/tree/master/hardware/displays/U8G2 (https://github.com/nkolban/esp32-snippets/tree/master/hardware/displays/U8G2)
- [esp_cam] esp idf Kamera Bibliothek: https://github.com/igrr/esp32-cam-demo.git
- [arduino_programmer] Arduino Uno als Programmer: https://create.arduino.cc/projecthub/arjun/programming-attiny85-with-arduino-uno-afb829 (https://create.arduino.cc/projecthub/arjun/programming-attiny85-with-arduino-uno-afb829)
- [eagle] https://www.autodesk.co.uk/products/eagle/overview
- [twi_implementation] https://github.com/rambo/TinyWire
- [attiny254585] https://ww1.microchip.com/downloads/en/DeviceDoc/Atmel-2586-AVR-8-bit-Microcontroller-ATtiny25-ATtiny45-ATtiny85_Datasheet.pdf (https://ww1.microchip.com/downloads/en/DeviceDoc/Atmel-2586-AVR-8-bit-Microcontroller-ATtiny25-ATtiny45-ATtiny85_Datasheet.pdf)

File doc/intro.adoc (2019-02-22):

== Vorwort

Im Rahmen der Master-Projektarbeit im Wintersemester 2018/19 wurde eine Modular-Recon-Drone
(modulare Aufklärungsdrohne) entwickelt. Auf Abbildung <<fig:drohne>> ist der finale Aufbau 
gezeigt. Bei der Architektur der Hard- und Software wurde auf einen modularen Aufbau geachtet,
um die einzelnen Komponenten leicht gegen Alternativen austauschen zu können. So wurde zum Beispiel
das Ansteuern der Motoren in ein eigenes Modul ausgelagert, das über ein TWI-Interface angesprochen
werden kann. Die Drohne bietet eine simple Schnittstelle über die sie gesteuert werden kann.
Auch hier kann das Steuersystem leicht ausgetauscht oder angepasst werden. Im Rahmen dieses Projekts
wurden zwei Steuersysteme entwickelt, welche als Basis für die Entwicklung weiterer Eingabemethoden
genutzt werden können. Um die Drohne auch aus der Ferne zu steuern, verfügt sie über ein Kameramodul.

.Modular-Recon-Drone
[[fig:drohne,{counter:fig}]]


Im Folgenden werden die einzelnen Komponenten der Drohne und ihr Aufbau dokumentiert. 
Anschließend werden die Steuersysteme vorgestellt.

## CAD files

main_control_unit/components/u8g2/sys/arduino/u8g2_full_buffer/SwitchBox/board.dxf
60
40
52
8
24
80
30
32
25
100
190
4
12
6
14

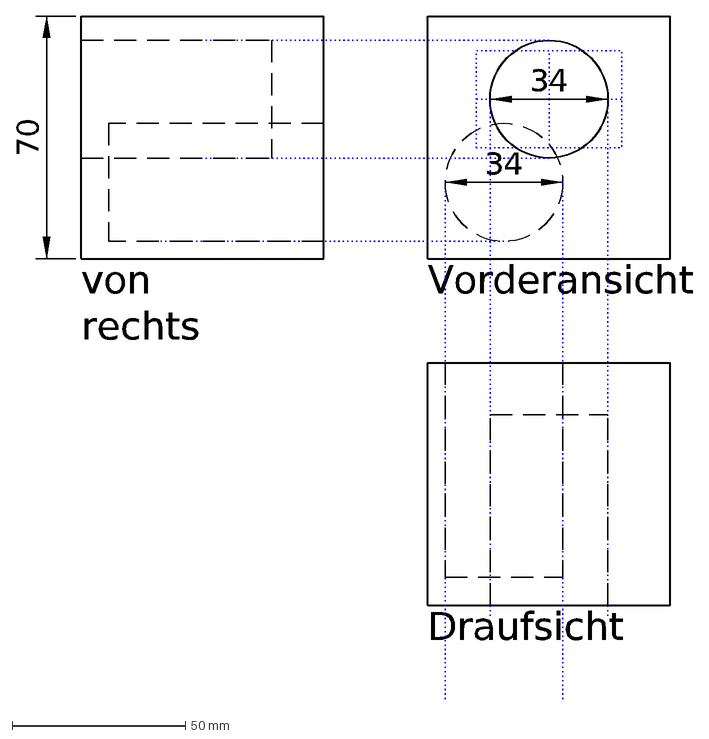
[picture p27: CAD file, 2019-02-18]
main_control_unit/components/u8g2/sys/arm/stm32l031x6/clock_cube.dxf
Draufsicht
Vorderansicht
von rechts
70
34

main_control_unit/components/u8g2/sys/arm/stm32l031x6/clock_2.dxf
65
Draufsicht
Vorderansicht
von unten
von rechts
von links
14
30
32
35
75
55
10
12
16
11
22
34
28
29
18
93
19
43
15
68
60
57
150
Holzbohrer: 2.5, 8, 10, 12, 16, 32mm
8
7
6
2.5mm

main_control_unit/components/u8g2/sys/arm/stm32l031x6/clock.dxf
65
32
28
16
Draufsicht
Vorderansicht
von unten
von rechts
von links
14
6
45
60
30
20
8
35
75
55
10
12

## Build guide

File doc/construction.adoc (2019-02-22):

== Aufbau der Drohne

In diesem Abschnitt werden die einzelnen Komponente der Drohne beschrieben.
Zuerst wird auf die Hauptkontrolleinheit eingegangen. Anschließend wird die
Motorsteuerung beschrieben, gefolgt vom Kameramodul und dem Bildschirm.
Abschließend wird auf die Stromversorgung und das erstellte PCB eingegangen.

=== Main Control Unit
Die MCU ist die Hauptkontrolleinheit. Ihre Hauptaufgaben sind:

* Hosten eines Access Points
* Hosten eines UDP-Sockets
* Hosten eines TCP-Servers
* Hosten des TWI Master

Grundlage der MCU bildet ein _Espressif ESP32_ (DevKit v.1, siehe Abbildung <<fig:esp32_devkitv1>>).

.Espressif ESP32 DevKit v1 Development Board
[[fig:esp32_devkitv1, {counter:fig}]]


Im Detail stellt der ESP32 einen Access Point mit WPA2 PSK Sicherung zur Verfügung. Das Passwort des Access Points wird hierbei mittels 
Hardware RNG in Form einer achtstelligen, positiven Ganzzahl generiert. 
Das Passwort und die SSID des Access Points werden auf dem Bildschirm dargestellt (siehe Abschnitt <<sec:oled_screen>>). 

==== Entwicklung
Der ESP32 ist mit 244 Mhz und zwei CPU Kernen ein potenter 32 Bit Microcontroller. Zudem verfügt der Controller 
über eine Vielzahl an Schnittstellen. Neben den oben erwähnten Funktionalitäten verfügt der ESP noch über: 

* Bluetooth 4.2 (inkl. BLE)
* 18 ADC Kanäle mit 12 bit Auflösung
* 2 DAC mit 8 bit Auflösung
* 10 Touch Sensoren (Kapazitiv)
* 4 SPI Controller
* 2 TWI Controller
* 2 I^2^S Controller
* 3 UART Controller
* SD/SDIO/MMC/eMMC Host Controller 
* CAN Bus 2.0
* Motor und LED PWM
* Hall Effekt Sensor
* Hardwarebeschleunigte Kryptografie (AES, SHA-2, RSA, ECC, RNG)

Software für den ESP32 kann mit Hilfe der Arduino IDE entwickelt werden. Jedoch ist das SDK des Herstellers, auch als ESP-IDF bezeichnet, vorzuziehen, da 
sie der Arduino IDE gegenüber wesentlich mächtiger ist. 

==== ESP-IDF
Die Installation der ESP-IDF ist für gängige Betriebssystemen auf der Herstellerseite (siehe <<esp_idf_install>>) dokumentiert.
Dem SDK liegt zusätzlich noch eine Ansammlung an Beispielprojekten, sortiert nach Modulen (Wifi, Bluetooth, GPIO, etc), bei.
Diese sind, wie auch die Komponenten der SDK selbst, umfangreich und gut dokumentiert (siehe Header-Dateien).
Beim Aufsetzen eines neuen Projekts empfiehlt es sich, eines der Beispielprojekte zu nehmen (im Zweifelsfall das Hello World), da die ESP-IDF bereits eine auf _Make_ basierende Buildchain anbietet. 

Diese lässt sich mit folgenden Befehlen bedienen (aus dem Projektverzeichnis heraus):

* make menuconfig -> TUI zur Konfiguration des Projektes (sdkconfig.h)
* make all -> Bau des Projektes
* make flash -> ggf. Bau des Projektes und Flashen des ESP
* make clean -> Bereinigung des Build-Verzeichnisses
* make monitor -> Starten des pythonbasierten seriellen Monitors

Um die Buildchain des SDK ohne Einschränkungen verwenden zu können, wird eine Python 2 Installation benötigt. Diese sollte entsprechend unter Verwendung von _menuconfig_ unter _SDK Tool Configuration_ -> _Python 2 Interpreter_ gesetzt werden.

Danach muss noch der serielle Port, unter dem der ESP im Betriebssystem angebunden wird, konfiguiert werden. Dies geschieht unter _Serial flasher options_ -> _Default serial port_.

Die ESP-IDF nutzt das Echtzeitbetriebssystem FreeRTOS (siehe <<freertos>>). Dieses stellt Tasks, Message Queues zur Intertaskkommunikation und Tasksynchronisationsmechanismen (Mutex, etc) zur Verfügung.

Als TCP/IP Stack wird LwIP (siehe <<lwip>>) genutzt. Es handelt sich um eine leichtgewichtige Implementierung, deren Fokus auf Embedded Systems liegt. Angelehnt ist die API an die der POSIX Sockets.

==== MCU Software
Die Struktur des Projektes stellt sich wie folgt dar:

* main_control_unit
** components
*** camera 
*** u8g2
** main

Für das Ansprechen der Kamera- (siehe Abschnitt <<sec:camera_module>>) und Display-Komponenten (siehe Abschnitt <<sec:oled_display>>) wurden 
jeweils entsprechende externe Bibliotheken verwendet (näheres in den entsprechenden Abschnitten). Diese sind, wie andere externe Bibliotheken im Allgemeinen, im Ordner _components_ abgelegt. 
Der eigentliche Code der Drohne befindet sich im Ordner _main_. Der Aufbau der eigentlichen Projektdateien ist in Abbildung <<fig:mcu_structure>> gezeigt.

.MCU Code Struktur
[[fig:mcu_structure, {counter:fig}]]
[ditaa, "mcu_structure"]
....
+---------+                      +---------+
| drone.c |----------------------| drone.h |
+---------+                      +---------+
                                   | | | |
        /--------------------------/ | | \----------------------------\
        |                   /--------/ \-------\                      |
        |                   |                  |                      |
+---------------+  +-----------------+  +--------------+  +-------------------------+
| accesspoint.c |  | camera_module.c |  | i2c_master.c |  | udp_motor_data_server.c |
+---------------+  +-----------------+  +--------------+  +-------------------------+
....

Zunächst werden die Komponenten initialisiert. Nach der Initialisierung werden die einzelnen Module (accesspoint.c, etc) gestartet. 
Hierbei werden jeweils für die einzelnen Module Tasks generiert, um möglichst parallel zu laufen.

===== Main
Neben der Initialisierung der einzelnen Software-Module, ist hier auch der _Systemeventhandler_ und die Bildschirmaktualisierung untergebracht. 
Der _Eventhandler_ fängt die einzelnen Zustände des Access Points ab (Client verbindet sich, Client trennt sich) und setzt entsprechende Flags in der definierten Systemeventgroup. 

Exemplarisch ist die Ablaufreihenfolge der Access Point Events in Abbildung <<fig:event_handling_diagram>> gezeigt.

.Ablauf, Start des AP, Client verbindet, Client trennt sich
[[fig:event_handling_diagram, {counter:fig}]]
[plantuml, target="event_handling_diagram"]
....
@startuml
"Access Point" -> "System Event Handler": SYSTEM EVENT AP START
"System Event Handler" -> "UDP Motor Data Server": server start
"System Event Handler" -> "Camera Module": camera module start
"Access Point" -> "System Event Handler": SYSTEM_EVENT AP STACONNECTED
"System Event Handler" -> "System Event Group": Set Bit CLIENT CONNECTED
"Access Point" -> "System Event Handler": SYSTEM_EVENT AP STADISCONNECTED
"System Event Handler" -> "System Event Group": Clear Bit CLIENT CONNECTED
@enduml
....

Mit Hilfe der _Eventgroup_ kann nun ein entsprechender Text auf dem Display angezeigt werden, abhängig davon, ob ein Nutzer verbunden ist oder nicht (siehe Abbildung <<fig:display_textupdate>>). 

.Display Textupdate
[[fig:display_textupdate, {counter:fig}]]
[plantuml, target="display_update_diagram"]
....
@startuml
start

if (xEventGroupGetBits(system_event_group) & CLIENT_CONNECTED) then (true)
        :show connected and current rssi;
else (false)
        :show ssid and password;
endif

stop
@enduml
....

===== Access Point Modul
Das Access Point Modul übernimmt neben der Initialisierung des Wifi auch die Initialisierung des TCP/IP Stacks. Während des Initialisierungsvorgangs wird mit Hilfe des RNG, wie bereits erwähnt, ein acht stelliges numerisches Passwort generiert. 
Die Konfiguration des Access Points ist in Tabelle <<table:ap_config>> aufgeführt. 

.AP Konfiguration
[[table:ap_config]]
|===
| SSID | Recon Drone
| Kanal | 0
| Authmode | WPA_WPA2_PSK
| Versteckt | nein
| Max. Verbindungen | 1
| Beacon Interval | 100
| IP | 192.168.4.1
|===

===== I^2^C Master Modul
Zum Einen initialisiert das Modul den Bus als Master und startet den Task zum Senden der Motorsteuerdaten an die jeweiligen ATTinys (siehe Abschnitt <<sec:attiny>>). 
Die Motorsteuerdaten werden über eine Messagequeue, die vom UDP Socket (siehe Abschnitt <<sec:udp_motor_data>>) befüllt wird, geliefert.

.TWI Bus Konfiguration
|===
| Mode | Master
| SDA Leitung | Pin 32
| SCL Leitung | Pin 33
| Taktfrequenz | 100 kHz
| TX Puffer | Nein
| RX Puffer | Nein
|===

Zum Anderen wird das Display initialisiert und aus dem _Standby_ aufgeweckt.

===== Camera Modul
Neben der Initialisierung der Kamera mit Hilfe der externen Bibliothek (siehe Abschnitt <<sec:camera_module>>), wird im Modul 
noch ein Task gestartet, der mittels TCP-Server auf einkommende Verbindungen von Seiten der Steuereinheit wartet. 
Nach Verbindungsaufbau sendet der TCP-Server konstant die aus der Kamera ausgelesenen Bilddaten an den Client.
Sobald über die _Eventgroup_ signalisiert wurde, dass der Client die Verbindung unterbrochen hat, wartet der TCP-Server auf einen erneuten Verbindungsaufbau. Dies geschieht zum Einen über die _Eventgroup_ und zum Anderen über das Timeout der Schreiboperation des Sockets.

.Kamera TCP-Server Ablauf
[[fig:camera_tcp_server, {counter:fig}]]
[plantuml, "camera_tcp_server", align="center"]
....
@startuml
start
:Init Socket;
repeat
        :Accept connection;
        repeat
                :camera run\n ->request data;
                :socket write data;
        repeat while (client connected or \nwrite without error)
repeat while (While ESP running)
@enduml
....

.Kamera und TCP Socket Konfiguration
[[table:camera_tcp_config, {counter:fig}]]
|===
| Pixel Format | Grayscale
| Auflösung | 160 x 120
| TCP Port | 1234
|===

[NOTE]
Die Wahl des Grayscale-Formats und die geringe Auflösung (bei Graustufen jedoch auch 320 x 240 möglich) sind darauf zurückzuführen, dass der ESP32 nicht über 
ausreichend internen RAM verfügt, um die Bilddaten vor dem Senden über TCP zwischenzupuffern (siehe Abschnitt <<sec:vision_external_ram>>). 

[[sec:udp_motor_data]]
===== UDP Motor Data Server Module
Initialisiert und startet einen UDP Socket, der die Motordaten des Clients empfängt und an eine Messagequeue übergibt.

[[sec:attiny]]
=== Motor Controller
Um die beiden Motoren anzusteuern, wurde ein ATTiny25 Mikrocontroller pro Motor verwendet.
Über das TWI wird den beiden Mikrocontrollern die gewüschte Richtung und Geschwindigkeit vom
ESP32 mitgeteilt. Sie werden über die Adressen 0x01 und 0x02 angesprochen. Auf Abbildung
<<fig:attiny25_pinout>> sind die Pins für die Takt- (_SCL_) und Datenleitung (_SDA_) des TWIs gezeigt.
Der genau Schaltplan, wie die ATTinys mit dem ESP32 verbunden sind, ist im Anhang aufgeführt (siehe Abbildung <<fig:full_schematic>>).
Da die ATTinys nicht über eine Hardwareimplementierung des TWIs verfügen, musste sie in Software realisiert
werden. Hierzu wurde eine bereits existierende Implementation von <<twi_implementation>> verwendet, welche
die USI Schnittstelle der Mikrocontroller passend für das TWI konfiguriert (siehe <<attiny254585>>).

.ATTiny25 Pinout
[[fig:attiny25_pinout,{counter:fig}]]


Die ATTinys erwarten ein Byte, in dem die Richtung und die Geschwindigkeit kodiert sind.
Das höchstwertige Bit kodiert die Richtung. Wird eine _0_ empfangen, wird der Pin _DIR0_ auf _HIGH_
gesetzt und der Pin _DIR1_ auf _LOW_ gesetzt. Wird eine _1_ empfangen, wird enstprechend Pin _DIR0_
auf _LOW_ und Pin _DIR1_ auf _HIGH_ gesetzt. Diese beiden Pins sind nie zeitgleich _HIGH_. Durch die 
unteren sieben Bit des empfangenen Bytes wird die Geschwindigkeit in Prozent angegeben. Intern
betreiben die Mikrocontroller hiermit eine Pulsweitenmodulation, welche 127 Schritte unterstützt.
Dieses Signal wird über den Pin _PWM_ ausgegeben. Zwischen den ATTinys und den Motoren wurde eine
H-Brücken eingebaut, um die Motoren mit 11.1V betreiben zu können. Wie die beiden Mikrocontroller 
über die H-Brücke mit den beiden Motoren verbunden sind, ist auf Abbildung <<fig:full_schematic>>
im Anhang gezeigt. Der Programmcode für beide Mikrocontroller ist identisch. Die Adresse für das
TWI wird über das Define-Flag _address_ gesetzt werden. Um das Kompilieren des Programms für die 
beiden Mikrocontroller zu erleichtern, wurde ein Makefile erstellt. Durch den _make_
Befehl werden die Programme der beiden Mikrocontroller gebaut. Durch _make flash_L_ und
_make flash_R_ wird entsprechend das Programm für die linke und rechte Motorsteuerung 
auf die Mikrocontroller geschrieben. Damit das Kompilieren und Programmieren der ATTinys
funktioniert, müssen die AVR-Entwicklungstools _avr-gcc_, _avr-objcopy_ und _avrdude_ 
installiert sein. Bevor die Programme auf die Mikrocontroller geschrieben werden können,
muss sichergestellt werden, dass der serielle Port des Programmers richtig gesetzt ist. Hierzu
kann das _-P_-Flag des _avrdude_-Befehls angepasst werden. Je nachdem, welche Programmer 
verwendet wird, muss auch das _-c_-Flag angepasst werden. In der aktuellen Version wird
davon ausgegangen, dass mit einem AVRISP programmiert wird (siehe <<arduino_programmer>>).

[[sec:camera_module]]
=== Kameramodul

Das verwendete Kameramodul basiert auf dem OV7725 VGA Sensor von Omnivision. Dieses Modul
erfüllt die gängigen Marktansprüche an PC-Multimedia- und Smartphone-Kameras. Es kann in 
Temperaturen von -20°C bis 70°C betrieben werden und passt sich automatisch an schlechte
Lichtverhältnisse an. Es unterstützt eine maximale Auflösung von 640x480 Pixel und unterstützt
bis zu 60 FPS. Die Bilddaten können in verschiedenen Formaten über das SCCB Interface erhalten
werden (vgl. <<ov7725>>).

.Kameramodul OV7725
[[fig:camera_module, {counter:fig}]]


Zum Ansprechen des Kameramoduls wurde eine bereits existierende Bibliothek verwendet
(vgl. <<esp_cam>>). In der folgenden Tabelle ist beschrieben, wie das Kameramodul mit dem ESP32
verbunden wurde. Es ist anzumerken, dass die Verbindung zwischen dem Kameramodul und dem ESP32
möglichst kurz zu halten ist. Wird die Verbindung zu lang, wird lediglich Rauschen vom ESP32
empfangen.

.Anschluss der Kamera am ESP32
[cols="24%,24%,4%,24%,24%", align="center"]
|===
|Kamera Pin |ESP32 Pin | |Kamera Pin | ESP32 Pin

|SIOC
|GPIO23
|
|SIOD
|GPIO25

|XCLK
|GPIO27
|
|VSYNC
|GPIO22

|HREF
|GPIO26
|
|PCLK
|GPIO21

|D2
|GPIO35
|
|D3
|GPIO17

|D4
|GPIO34
|
|D5
|GPIO5

|D6
|GPIO39
|
|D7
|GPIO18

|D8
|GPIO36
|
|D9
|GPIO19

|RESET
|GPIO15
|
|PWDN
| (über 10kOhm Widerstand auf GND)

|3.3V
|3.3V
|
|GND
|GND
|===

[[sec:oled_display]]
=== Bildschirm
Verwendung findet ein monochromes OLED-Display mit einer Auflösung von 128x64 Pixel. Dieses basiert auf dem verbreiteten SSD1306 Controller. 

.Oled Diplay 128x64, SSD1306
[[fig:oled_display, {counter:fig}]]


Das Display wird hierbei über einen TWI-Bus angebunden. Entsprechend setzt sich der Pinout wie folgt zusammen:

* GND: Ground, Masse
* VCC: Spannung, 3,3V - 5V
* SDL: TWI, Datenleitung
* SCL: TWI, Taktleitung

Zur Ansteuerung des Displays wird auf die *u8g2* Bibliothek für monochrome LCD- und OLED Bildschirme zurückgegriffen. Diese unterstützt eine Vielzahl an Display Controllern. Die Standardimplementierung ist für die Verwendung unter Arduinos vorgesehen. Jedoch ist die Bibliothek mit hoher Abstraktion aufgebaut und bietet eine Schnittstelle um hardwarespefizische Funktionalitäten anderer Microcontroller wie dem ESP32 zu implementieren. 
Für den ESP32 existiert diese Implementierung bereits unter dem Namen _u8g2_esp_ (siehe <<u8g2_esp>>). Jedoch wurde die Implementierung so 
vorgesehen, dass sie neben dem Ansteuern des Bildschirms auch die Initialisierung des TWI-Controllers übernimmt. Da dies im Projekt bereits geschieht, wurde der entsprechende Teil in der Implementierung entfernt. Auch wurde der verwendete TWI-Controller angepasst. Ursprünglich sah die Implementierung 
TWI-Controller 2 vor, die Drohne nutzt jedoch TWI-Controller 1. 

=== Stromversorgung
Im gesamten Projekt werden drei Versorgungsspannungen benötigt: 3.3V für das Kameramodul, 5V für die MCU und die Motorsteuerung, sowie
bis zu 12V für die Motoren. Auf Abbildung <<fig:full_schematic>> im Anhang ist gezeigt, wie die einzelnen Versorgungsspannungen von
der Batterie erhalten werden. Die Motoren werden direkt mit der Batteriespannung betrieben. Um die 5V für die MCU und die Motorsteuerung
zu erhalten, wurde der Spannungsregler 7805 verwendet. Er benötigt mindest 7V als Eingangspannung, um 5V als Ausgungsspannung zu erzeugen.
Um ein Schwanken der Betriebsspannungen zu vermeiden wurden Kondensatoren vor dem Ein- und Ausgang des Spannungsreglers platziert. Die für
das Kameramodul benötigten 3.3V werden vom ESP32 erzeugt. Bei der Realisierung dieses Projektes fiel die Entscheidung auf einen 3-Zellen LiPo-Akku,
wodurch 11.1V als Batteriespannung anliegen.

=== Schaltplan und PCB
Zu Beginn des Projekts wurden die einzelnen Komponenten auf einem Breadboard verkabelt, getestet und anschließend auf einer
Lochrasterplatine in einem Prototypen verlötet. Dieser Prototyp ist auf Abbildung <<fig:prototyp>> zu sehen.

.Lochrasterplatine
[[fig:prototyp, {counter:fig}]]


Nachdem die Funktionalität des Aufbaus der Hardware verifiziert wurde, wurde ein PCB mit der Eagle Software von Autodesk designed
(siehe <<eagle>>). Die Eagle-Projektdateien sind im Ordner _schematic_and_pcb_ zu finden. Anschließend wurde JLCPCB (siehe <<jlcpcb>>)
mit der Fertigung des PCBs beauftragt. Das fertig bestückte PCB ist auf Abbildung <<fig:pcb>> gezeigt.

.Fertige bestücktes PCB
[[fig:pcb, {counter:fig}]]


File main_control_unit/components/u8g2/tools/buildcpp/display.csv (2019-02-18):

# 1. device name
# 2. pinset
# 3. constructor name w/o prefix
u8x8_d_ssd1306_128x64_noname | 4WSWSPI | SSD1306_128X64_4W_SW_SPI
u8x8_d_ssd1306_128x64_noname | 4WHWSPI | SSD1306_128X64_4W_HW_SPI
u8x8_d_ssd1306_128x64_noname | 3WSWSPI | SSD1306_128X64_3W_SW_SPI
u8x8_d_ssd1306_128x64_noname | SSDSWI2C | SSD1306_128X64_SW_I2C
u8x8_d_ssd1306_128x64_noname | 6800 | SSD1306_128X64_6800
u8x8_d_ssd1306_128x64_noname | 8080 | SSD1306_128X64_8080

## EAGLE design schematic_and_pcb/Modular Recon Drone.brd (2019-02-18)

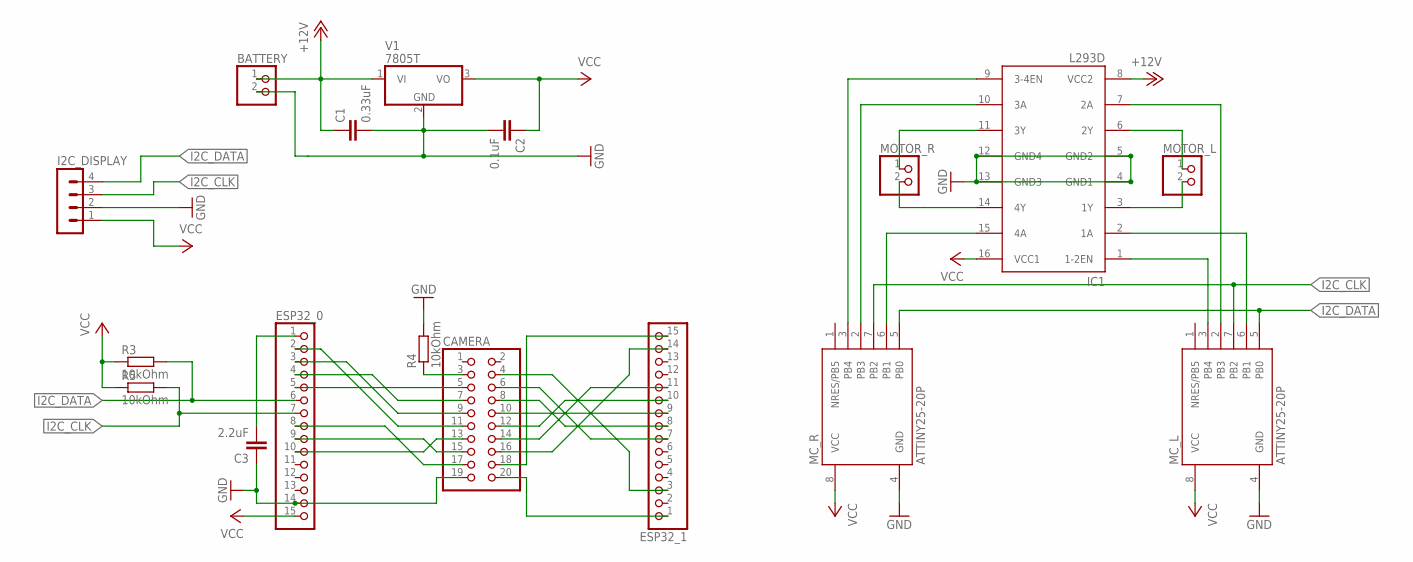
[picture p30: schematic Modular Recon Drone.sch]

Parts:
BATTERY: PINHD-1X2; 1X02
C1: 0.33uF; C025-050X050
C2: 0.1uF; C025-050X050
C3: 2.2uF; C025-050X050
CAMERA: PINHD-2X10; 2X10
ESP32_0, ESP32_1: PINHD-1X15; 1X15
I2C_DISPLAY: MA04-1
IC1: L293D; DIL16
MC_L: ATTINY25-20P; PDIP08_300MIL
MC_R: ATTINY25-20P; PDIP08_300MIL
MOTOR_L: PINHD-1X2; 1X02
MOTOR_R: PINHD-1X2; 1X02
R3, R4, R5: 10kOhm; 0204/5
V1: 7805T; TO220H

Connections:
+12V: BATTERY.1, C1.1, IC1.8 (VCC2), V1.1 (VI)
GND: BATTERY.2, C1.2, C2.2, C3.1, CAMERA.19, ESP32_0.14, I2C_DISPLAY.2, IC1.4 (GND1), IC1.5 (GND2), IC1.12 (GND4), IC1.13 (GND3), MC_L.4 (GND), MC_R.4 (GND), R4.2, V1.2 (GND)
I2C_CLK: ESP32_0.7, I2C_DISPLAY.3, MC_L.7 (PB2), MC_R.7 (PB2), R5.2
I2C_DATA: ESP32_0.6, I2C_DISPLAY.4, MC_L.5 (PB0), MC_R.5 (PB0), R3.2
unnamed: IC1.3 (1Y), MOTOR_L.2
unnamed: IC1.6 (2Y), MOTOR_L.1
unnamed: IC1.14 (4Y), MOTOR_R.2
unnamed: IC1.15 (4A), MC_R.6 (PB1)
unnamed: IC1.11 (3Y), MOTOR_R.1
unnamed: IC1.2 (1A), MC_L.6 (PB1)
unnamed: IC1.10 (3A), MC_R.2 (PB3)
unnamed: IC1.7 (2A), MC_L.2 (PB3)
unnamed: IC1.9 (3-4EN), MC_R.3 (PB4)
unnamed: IC1.1 (1-2EN), MC_L.3 (PB4)
unnamed: CAMERA.20, ESP32_1.1
unnamed: CAMERA.18, ESP32_1.15
unnamed: CAMERA.16, ESP32_1.14
unnamed: CAMERA.14, ESP32_1.11
unnamed: CAMERA.12, ESP32_1.10
unnamed: CAMERA.10, ESP32_1.9
unnamed: CAMERA.8, ESP32_1.8
unnamed: CAMERA.6, ESP32_1.7
unnamed: CAMERA.4, ESP32_1.3
unnamed: CAMERA.17, ESP32_0.8
unnamed: CAMERA.15, ESP32_0.9
unnamed: CAMERA.13, ESP32_0.10
unnamed: CAMERA.11, ESP32_0.2
unnamed: CAMERA.9, ESP32_0.3
unnamed: CAMERA.7, ESP32_0.4
unnamed: CAMERA.5, ESP32_0.5
unnamed: CAMERA.3, R4.1
unnamed: C3.2, ESP32_0.1
VCC: C2.1, ESP32_0.15, I2C_DISPLAY.1, IC1.16 (VCC1), MC_L.8 (VCC), MC_R.8 (VCC), R3.1, R5.1, V1.3 (VO)

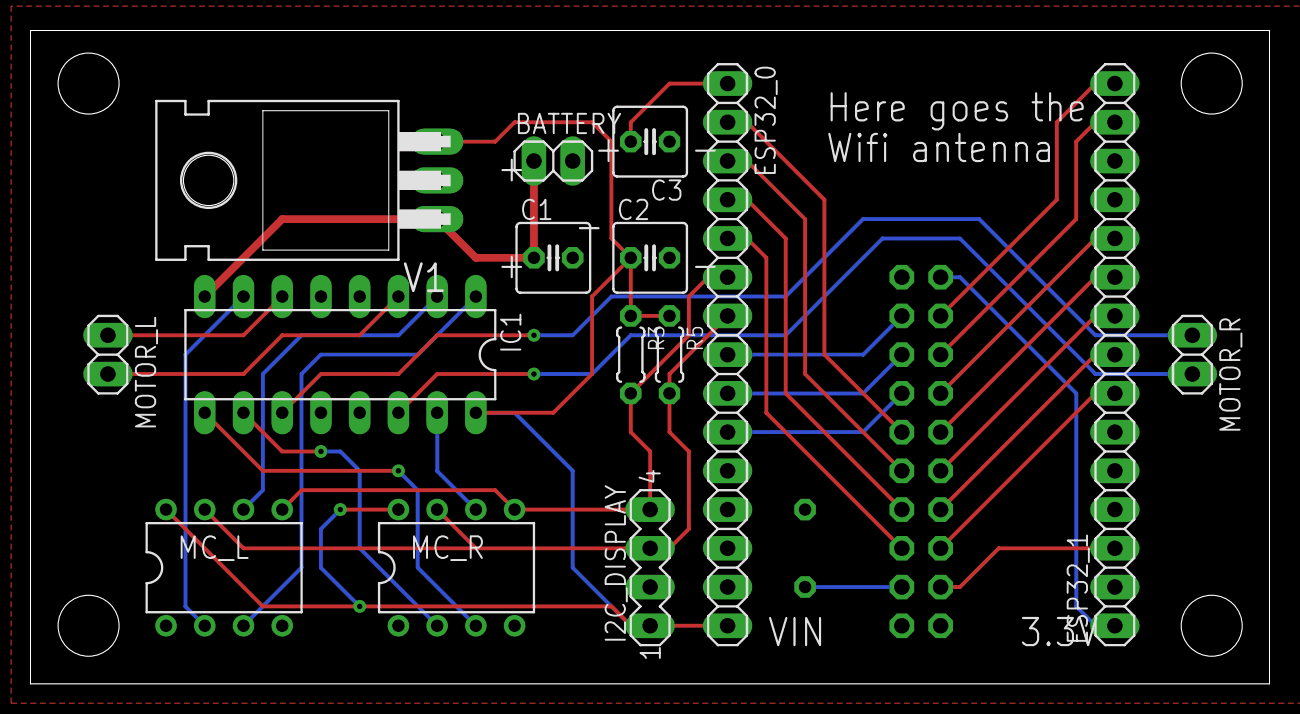
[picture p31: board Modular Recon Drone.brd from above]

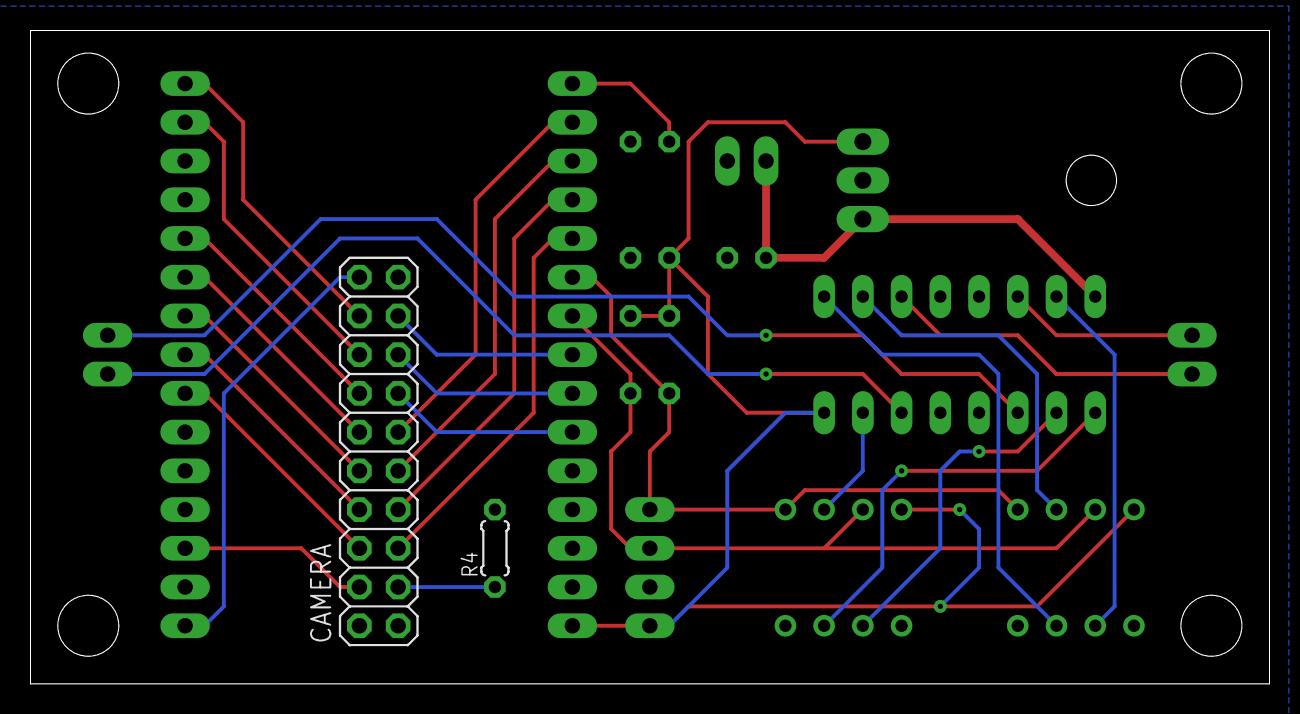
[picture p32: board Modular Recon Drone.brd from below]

Board: 2 copper layers, 81.3 x 42.9 mm, 17 parts (2 on the bottom side), 33 nets.

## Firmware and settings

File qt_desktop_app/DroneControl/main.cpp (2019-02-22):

#include <QGuiApplication>
#include <QQmlContext>
#include <QQmlApplicationEngine>
#include "clienthandle.h"

int main(int argc, char *argv[])
{
    QCoreApplication::setAttribute(Qt::AA_EnableHighDpiScaling);

    QGuiApplication app(argc, argv);
    qmlRegisterType<ClientHandle>("Drone.ClientHandle", 1, 0, "ClientHandle");
    QQmlApplicationEngine engine;
    engine.load(QUrl(QStringLiteral("qrc:/main.qml")));
    if (engine.rootObjects().isEmpty())
        return -1;

    return app.exec();
}

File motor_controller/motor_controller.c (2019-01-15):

#include <avr/io.h>
#include <avr/interrupt.h>

#include "usi_twi_slave.h"

#ifndef address
#   define address 0x01
#endif

void initializeI2C()
{
    usiTwiSlaveInit(address);
    sei();
}

void initializePWM()
{
    // Timer 1
    TCCR1 = (1 << CS10); // no prescaler
    GTCCR = (1 << COM1B1) | (1 << PWM1B); // clear OC1B on compare
    OCR1B = 0; // duty cycle // pulse width
    OCR1C = 127; // frequency

    // Set PWM Pin as Output
    DDRB |= (1 << PIN4);
}

void initializeDirectionPins()
{
    DDRB |= (1 << PIN1) | (1 << PIN3);
    PORTB &= ~((1 << PIN1) | (1 << PIN3));
}

void initialize()
{
    initializeI2C();
    initializePWM();
    initializeDirectionPins();
}

void controlMotor(uint8_t command)
{
    OCR1B = (unsigned char)(127 * ((command & 0x7F) / 100.0));
    if (command & 0x80)
    {
        PORTB &= ~(1 << PIN1);
        PORTB |= (1 << PIN3);
    }
    else
    {
        PORTB &= ~(1 << PIN3);
        PORTB |= (1 << PIN1);
    }
}

int main()
{
    initialize();

    while (1)
    {
        controlMotor(usiTwiReceiveByte());
    }
}

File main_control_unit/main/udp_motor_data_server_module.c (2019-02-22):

#include "drone.h"

static const char* TAG = "udp_server";

static void server_task()
{
    struct sockaddr_in host_addr;
    int server_socket_desc;
    int err = 0;
    char rx_buffer[2];    

    host_addr.sin_addr.s_addr = htonl(INADDR_ANY);
    host_addr.sin_family = AF_INET;
    host_addr.sin_port = htons(SERVER_PORT);

    server_socket_desc = socket(host_addr.sin_family, SOCK_DGRAM, IPPROTO_IP);
    err = bind(server_socket_desc, (struct sockaddr*) &host_addr, sizeof(host_addr));

    if(err < 0)
    {
        ESP_LOGE(TAG, "Could not bind to udp socket");
        vTaskDelete(NULL);
    }

    struct sockaddr_in client_addr;
    socklen_t client_socket_len = sizeof(client_addr);
    
    struct MotorData motor_data;

    while(true)
    {

        int len = recvfrom(server_socket_desc, rx_buffer, sizeof(rx_buffer), 0, (struct sockaddr *) &client_addr, &client_socket_len);
        if(len < 0)
        {
            ESP_LOGE(TAG, "Could not successfully receive data from udp socket");
            break;
        }
        else
        {
            if(len == 2)
            {
                ESP_LOGI(TAG, "Received data from udp socket");
                uint motor_a_direction = (rx_buffer[0] & (1 << 7)) >> 7;
                int motor_a_speed_percent = (rx_buffer[0] & ~(1 << 7));
                uint motor_b_direction = (rx_buffer[1] & (1 << 7)) >> 7;
                int motor_b_speed_percent = (rx_buffer[1] & ~(1 << 7));

                motor_data.motor_a_speed_percent = motor_a_speed_percent;
                motor_data.motor_a_direction = motor_a_direction;
                motor_data.motor_b_speed_percent = motor_b_speed_percent;
                motor_data.motor_b_direction = motor_b_direction;

                xQueueSend(udp_to_i2c_com_queue, &motor_data, 0);
            }
        }

        vTaskDelay(port_delay_ms(25));
    }

    if(server_socket_desc != -1)
    {
        ESP_LOGI(TAG, "Went out of receive loop. Closing socket.");
        shutdown(server_socket_desc, 0);
        close(server_socket_desc);
    }
    esp_wifi_deauth_sta(0);
    vTaskDelete(NULL);
}

void server_start()
{
    ESP_LOGI(TAG, "Starting udp server task");
    xTaskCreate(server_task, "UDP Server Task", 4096, NULL, 5, NULL);
}

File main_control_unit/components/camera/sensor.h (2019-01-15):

/*
 * This file is part of the OpenMV project.
 * Copyright (c) 2013/2014 Ibrahim Abdelkader <i.abdalkader@gmail.com>
 * This work is licensed under the MIT license, see the file LICENSE for details.
 *
 * Sensor abstraction layer.
 *
 */
#ifndef __SENSOR_H__
#define __SENSOR_H__
#include <stdint.h>
#include "wiring.h"

#define OV9650_PID     (0x96)
#define OV2640_PID     (0x26)
#define OV7725_PID     (0x77)


typedef struct {
    uint8_t MIDH;
    uint8_t MIDL;
    uint8_t PID;
    uint8_t VER;
} sensor_id_t;

typedef enum {
    PIXFORMAT_RGB565,    // 2BPP/RGB565
    PIXFORMAT_YUV422,    // 2BPP/YUV422
    PIXFORMAT_GRAYSCALE, // 1BPP/GRAYSCALE
    PIXFORMAT_JPEG,      // JPEG/COMPRESSED
} pixformat_t;

typedef enum {
    FRAMESIZE_40x30,    // 40x30
    FRAMESIZE_64x32,    // 64x32
    FRAMESIZE_64x64,    // 64x64
    FRAMESIZE_QQCIF,    // 88x72
    FRAMESIZE_QQVGA,    // 160x120
    FRAMESIZE_QQVGA2,   // 128x160
    FRAMESIZE_QCIF,     // 176x144
    FRAMESIZE_HQVGA,    // 220x160
    FRAMESIZE_QVGA,     // 320x240
    FRAMESIZE_CIF,      // 352x288
    FRAMESIZE_VGA,      // 640x480
    FRAMESIZE_SVGA,     // 800x600
    FRAMESIZE_SXGA,     // 1280x1024
    FRAMESIZE_UXGA,     // 1600x1200
} framesize_t;

typedef enum {
    FRAMERATE_2FPS =0x9F,
    FRAMERATE_8FPS =0x87,
    FRAMERATE_15FPS=0x83,
    FRAMERATE_30FPS=0x81,
    FRAMERATE_60FPS=0x80,
} framerate_t;

typedef enum {
    GAINCEILING_2X,
    GAINCEILING_4X,
    GAINCEILING_8X,
    GAINCEILING_16X,
    GAINCEILING_32X,
    GAINCEILING_64X,
    GAINCEILING_128X,
} gainceiling_t;

typedef enum {
    SDE_NORMAL,
    SDE_NEGATIVE,
} sde_t;

typedef enum {
    ATTR_CONTRAST=0,
    ATTR_BRIGHTNESS,
    ATTR_SATURATION,
    ATTR_GAINCEILING,
} sensor_attr_t;

typedef enum {
    ACTIVE_LOW,
    ACTIVE_HIGH
} reset_polarity_t;

typedef void (*line_filter_t) (uint8_t *src, int src_stride, uint8_t *dst, int dst_stride, void *args);

#define SENSOR_HW_FLAGS_VSYNC        (0) // vertical sync polarity.
#define SENSOR_HW_FLAGS_HSYNC        (1) // horizontal sync polarity.
#define SENSOR_HW_FLAGS_PIXCK        (2) // pixel clock edge.
#define SENSOR_HW_FLAGS_FSYNC        (3) // hardware frame sync.
#define SENSOR_HW_FLAGS_JPEGE        (4) // hardware JPEG encoder.
#define SENSOR_HW_FLAGS_GET(s, x)    ((s)->hw_flags &  (1<<x))
#define SENSOR_HW_FLAGS_SET(s, x, v) ((s)->hw_flags |= (v<<x))
#define SENSOR_HW_FLAGS_CLR(s, x)    ((s)->hw_flags &= ~(1<<x))

typedef struct _sensor sensor_t;
typedef struct _sensor {
    sensor_id_t id;             // Sensor ID.
    uint8_t  slv_addr;          // Sensor I2C slave address.
    uint32_t hw_flags;          // Hardware flags (clock polarities/hw capabilities)

    // Line pre-processing function and args
    void *line_filter_args;
    line_filter_t line_filter_func;

    reset_polarity_t reset_pol; // Reset polarity (TODO move to hw_flags)

    // Sensor state
    sde_t sde;                  // Special digital effects
    pixformat_t pixformat;      // Pixel format
    framesize_t framesize;      // Frame size
    framerate_t framerate;      // Frame rate
    gainceiling_t gainceiling;  // AGC gainceiling

    // Sensor function pointers
    int  (*reset)               (sensor_t *sensor);
    int  (*set_pixformat)       (sensor_t *sensor, pixformat_t pixformat);
    int  (*set_framesize)       (sensor_t *sensor, framesize_t framesize);
    int  (*set_framerate)       (sensor_t *sensor, framerate_t framerate);
    int  (*set_contrast)        (sensor_t *sensor, int level);
    int  (*set_brightness)      (sensor_t *sensor, int level);
    int  (*set_saturation)      (sensor_t *sensor, int level);
    int  (*set_gainceiling)     (sensor_t *sensor, gainceiling_t gainceiling);
    int  (*set_quality)         (sensor_t *sensor, int quality);
    int  (*set_colorbar)        (sensor_t *sensor, int enable);
    int  (*set_whitebal)        (sensor_t *sensor, int enable);
    int  (*set_gain_ctrl)       (sensor_t *sensor, int enable);
    int  (*set_exposure_ctrl)   (sensor_t *sensor, int enable);
    int  (*set_hmirror)         (sensor_t *sensor, int enable);
    int  (*set_vflip)           (sensor_t *sensor, int enable);
    int  (*set_special_effect)  (sensor_t *sensor, sde_t sde);
} sensor_t;

// Resolution table
extern const int resolution[][2];

// Initialize the sensor hardware and probe the image sensor.
int sensor_init();

// Initialize the sensor state.
void sensor_init0();

// Reset the sensor to its default state.
int sensor_reset();

// Return sensor PID.
int sensor_get_id();

// Read a sensor register.
int sensor_read_reg(uint8_t reg);

// Write a sensor register.
int sensor_write_reg(uint8_t reg, uint8_t val);

// Set the sensor pixel format.
int sensor_set_pixformat(pixformat_t pixformat);

// Set the sensor frame size.
int sensor_set_framesize(framesize_t framesize);

// Enable/disable the colorbar mode.
int sensor_set_colorbar(int enable);

// Enable/disable the whitebal mode.
int sensor_set_whitebal(int enable);

// Enable/disable the agc mode.
int sensor_set_gain_ctrl(int enable);

// Enable/disable the aec mode.
int sensor_set_exposure_ctrl(int enable);

// Enable/disable the hmirror mode.
int sensor_set_hmirror(int enable);

// Enable/disable the vflip mode.
int sensor_set_vflip(int enable);

#endif /* __SENSOR_H__ */

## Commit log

2018-10-18 Initialize motor controll
2018-10-29 Now using C instead of C++. Using usiTwiSlave implementation from: https://github.com/rambo/TinyWire/tree/master Implements ATtiny25 Motorcontroll using I²C.
2018-10-30 Motor is now controlled using two seperate PWMs. Only two H-Bridges are used by one ATtiny. Pin3 can now be used to select either I²C Address 0x01 or 0x02.
2018-11-05 Motor does not spin on startup anymore! Change the starting duty cycle of Timer0 so both PWMs are off on startup
2019-01-07 Restructured project. Added ESP code base to repository. Redone makefile of motor_controller. Renamed files of motor_controller. Rebased README file to root. Added gitignore
2019-01-08 Now only uses one PWM.
2019-01-15 Included camera handling library for ov7725 and ov2640 camera modules. Implemented grayscale image streaming functionality. Altered camera library to send additional information to the camera module 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
2019-01-15 Removed esp based motor control which was added for debugging purposes as long as the i2c based motor control didnt work
2019-01-15 Made some code refactoring. Also changed the call sequence so the camera socket gets initialized when the AP is up
2019-01-15 Updated documentation. Added links to the screen and camera relevant code repositories
2019-01-16 Included i2c functions again
2019-01-16 Removed unused code (header of image). Altered port delay of i2c, udp server and camera tcp
2019-01-16 Code refactoring (Logging). Removed unused file led.c
2019-02-18 Added glossary, vision section. Added imgs directory. Wrote parts of camera and display modules hardware section
2019-02-18 Added u8g2 library
    [board.dxf, clock.dxf, clock_2.dxf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]
2019-02-18 Added description for the motor controller.
2019-02-18 Added eagle project with schematic and pcb layout.
    [Modular Recon Drone.brd, Modular Recon Drone.sch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]
2019-02-18 Added pcb images.
2019-02-18 Added description for power supply.
2019-02-18 Added description for pcb.
2019-02-20 - Changed wrapper esp32 library of u8g2 display library -> Removed init code of i2c bus and changed used i2c controller to I2C_NUM_0. - Refactored code - Added display output - Added random number ge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
2019-02-20 Fixed steering and camera rotation.
2019-02-20 Added camera pin connection table.
2019-02-20 Renamed Architektur to Aufbau der Drohne.
2019-02-21 Added alternative power supply in vision.adoc.
2019-02-22 Explained why the connection to camera should be short.
2019-02-22 Added breadboard prototype picture
2019-02-22 Added Lochraster und PCB png.
2019-02-22 replaced 1 with true
    [udp_motor_data_server_module.c]
